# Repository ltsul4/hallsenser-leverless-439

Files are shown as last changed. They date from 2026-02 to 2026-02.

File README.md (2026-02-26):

# Magnetic Leverless Controller (自作磁気接点レバーレス)

本プロジェクトは、磁気スイッチ（ホールセンサー）を採用した超低遅延・高機能な競技用レバーレスコントローラーの開発プロジェクトです。

卒業制作の一環として制作されており、進捗に合わせて随時コードやデータの更新を行います。

---

## 概要

従来の物理接点スイッチではなく、磁力による非接触検知を採用することで、物理的な摩耗を抑えつつ、ミリ単位での高度な入力制御を実現しています。

### 主な機能

* **ラピッドトリガー (Rapid Trigger)**
    指の上げ下げに即座に反応する超高速入力を実現。
* **可変作動点 (Actuation Point)**
    反応する深さを 0.1mm 単位でカスタマイズ可能。
* **Web Configurator**
    専用ソフト不要。ブラウザからリアルタイムに設定変更・モニタリングが可能。
* **SOCDクリーナー**
    競技ルールに準拠した同時押し処理（ニュートラル優先、後押し優先等）を実装。
* **コンボボタン機能**
    1つのボタンで複数のボタン同時押しを再現する補助機能（C1～C4）。
* **入力切断機能**
    設定中の誤入力を防ぐためのセーフティ機能。

---

## ハードウェア設計

設計データはすべて `PCB` フォルダ内に格納されています。

* **基板データ (PCB Design)**: 回路図および基板発注用のガーバーデータ。
* **筐体データ (Acrylic Case)**: レーザーカット用のアクリルパネル設計データ。

### 主要コンポーネント

* **MCU**: STM32F303CBT6
* **センサー**: GH39F ホールセンサー
* **スイッチ**: 
    * デフォルト: Gateron Magnetic Jade Ultra (3.2mmストローク)
    * 特別仕様: Gateron Magnetic Jade Pro (3.5mmストローク)
* **マルチプレクサ**: ADG708

> [!NOTE]
> 本リポジトリの標準ファームウェアは **3.2mmストローク (Jade Ultra)** に最適化されています。
> 3.5mmストロークのスイッチを使用する場合は、`main.c` 内の `TRAVEL_DISTANCE_MM` を `3.5f` に変更してビルドしてください。

---

## ディレクトリ構成

*(※必要に応じて追記してください)*

---

## 導入手順

### 1. ファームウェアの書き込み

1.  [STM32CubeProgrammer](https://www.st.com/ja/development-tools/stm32cubeprog.html) をダウンロードしてPCにインストールします。
2.  基板の裏面にある2つのボタンのうち、**上側のBOOTボタンを押しながら**PCとUSBケーブルで接続します。その後、STM32CubeProgrammerを起動します。
3.  画面右側の接続メニューから「USB」を選択し、「Port」のドロップダウンから適切なポート（例: `USB1`）を選んだ後、緑色の**「Connect」**ボタンをクリックして基板と接続します。

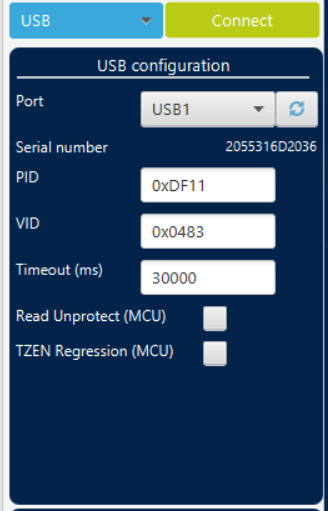
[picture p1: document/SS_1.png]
STM32CubeProgrammerの接続設定
    

4.  接続が成功したら、画面左上の「Open file」タブをクリックします。
5.  ファイル選択ダイアログが開くので、ビルド済みの `.bin` ファイル（例: `Leverless_Controller.bin`）を選択して開きます。

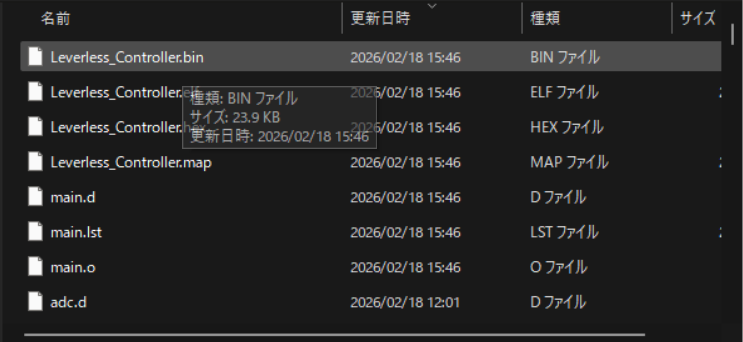
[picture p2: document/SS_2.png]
バイナリファイルの選択
    

6.  ファイルを読み込んだ後、「Download」ボタンをクリックしてファームウェアの書き込み（インストール）を実行します。
7.  **書き込み完了後、USBケーブルを一度抜き、ボタンを押さずにそのまま再度PCへ接続し直してください。**

### 2. 起動モードの選択

本デバイスには2つの動作モードがあります。

* **ゲームモード (通常起動)**
    そのままUSBを接続します。Windowsから「Xbox 360 Controller」として認識され、すぐにゲームで使用可能です。

* **設定モード (ボタン押下起動)**
    **UPボタン**を押しながらUSBを接続し、**数秒待ってから指を離します**。
    カスタムHIDデバイスとして認識され、ブラウザからの設定が可能になります。

### 3. Web Configurator による設定と使い方

1.  **設定モードで起動**
    前述の通り、UPボタンを押しながらデバイスをPCに接続します。
2.  **ブラウザで設定ページを開く**
    使用しているキースイッチに合わせて、以下のいずれかのページをブラウザ（Chrome/Edge推奨）で開きます。
    * **通常版 (3.2mm / Jade Ultra 等):** [WebDriver.htmlを開く](https://ltsul4.github.io/hallsenser-leverless-439/WebDriver/WebDriver.html)
    * **特別版 (3.5mm / Jade Pro 専用):** [WebDriver3.5.htmlを開く](https://ltsul4.github.io/hallsenser-leverless-439/WebDriver/WebDriver3.5.html)
3.  **デバイスの接続**
    画面右上の「接続」ボタンを押し、リストから該当する端末を選択して接続します。
    > ⚠️ **注意:** 端末選択画面で「Xbox 360 Controller」等の表示が出る場合は、設定モードでの接続が失敗しています。一度ケーブルを抜き、再度UPボタンを確実に押しながらつなぎ直してください。

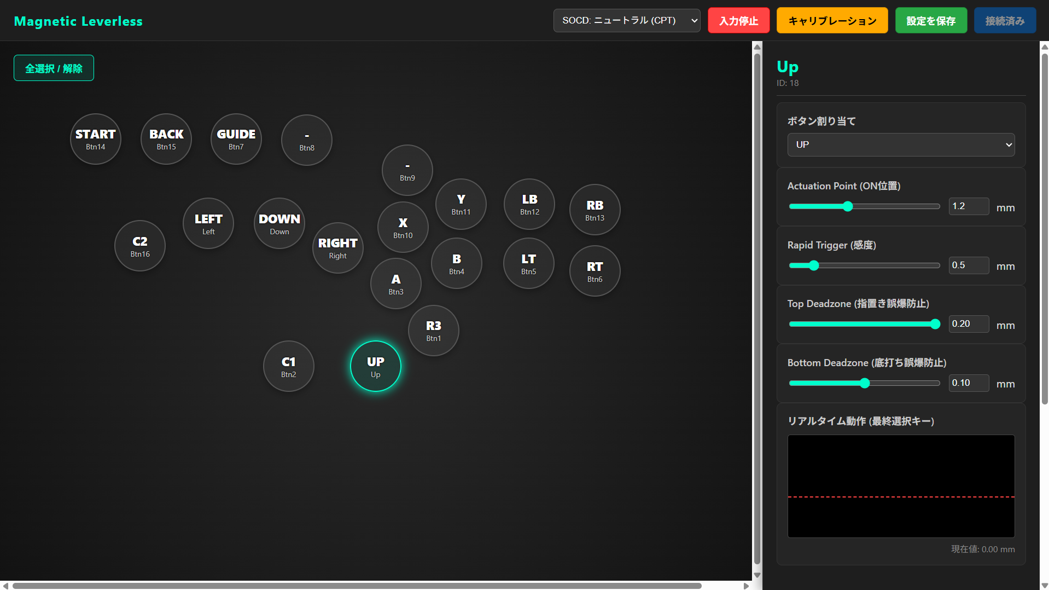
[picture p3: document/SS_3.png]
Web Configuratorのメイン画面
    

4.  **各種設定の調整**
    接続が完了すると、専用ドライバー上で以下の設定が可能になります。
    * **キーマッピング:** 各ボタンへの入力割り当てを変更。
    * **入力感度の調整:** Actuation Point (AP: 作動点)、Rapid Trigger (RT: 感度)、Top/Bottom Deadzone (DZ: 指置き・底打ち時の誤爆防止) をスライダーで設定。
    * **リアルタイム動作:** 右下のグラフで、選択したボタン（画像ではUPボタン）のトラッキング状況をリアルタイムに確認。
    * **SOCD設定:** 画面上部のメニューからSOCDクリーナーの方式を選択。

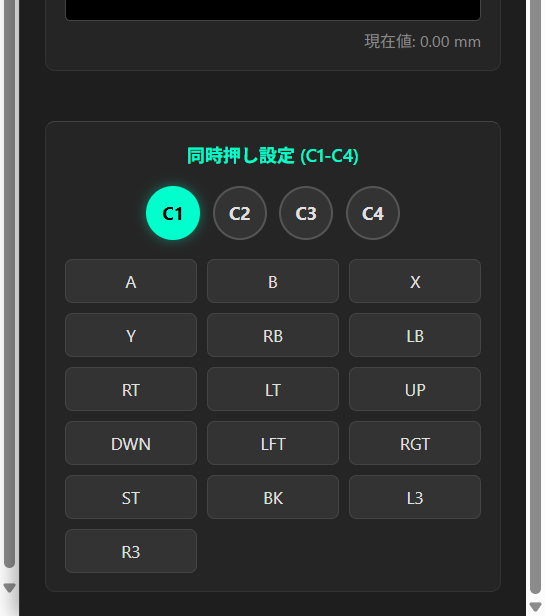
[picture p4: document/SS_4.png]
同時押し設定画面
    

5.  **同時押し設定 (コンボ機能)**
    画面を下にスクロールすると、C1～C4までの4種類の補助ボタンの設定項目があります。ここで複数ボタンの同時押しを登録することができます。
6.  **設定の保存**
    すべての設定が完了したら、画面右上の緑色の**「設定を保存」**ボタンを押します。
7.  **再起動して完了**
    保存完了後、**端末（USBケーブル）を一度抜き、そのまま再度つなぎ直す**ことで、設定がゲームモードに反映されます。

---

## 開発状況

- [x] ホールセンサーによるアナログ値の取得
- [x] ラピッドトリガー・可変作動点アルゴリズムの実装
- [x] WebHID / WebUSB による設定ツールの構築 (`WebDriver.html`)
- [x] Flashメモリへの設定保存機能
- [x] 同時押し（コンボ）ボタン機能の実装

---

## クレジット・参考元

本プロジェクトの制作にあたり、以下のプロジェクトを参考にさせていただきました。
* **参考元:** [kenyoshizoe/ember](https://github.com/kenyoshizoe/ember)

また、本プロジェクトのコードおよびドキュメントの一部は、**Gemini** を活用して作成されました。

---

## ライセンス

**MIT License**

本プロジェクトは卒業制作として継続的に開発されています。温かい目で見守っていただければ幸いです。

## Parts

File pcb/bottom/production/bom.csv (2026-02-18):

Designator | Footprint | Quantity | Value | LCSC Part #
H6 | MountingHole_2.2mm_M2 | 1 | MountingHole

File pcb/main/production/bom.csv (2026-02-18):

Designator | Footprint | Quantity | Value | LCSC Part #
C1, C11, C12, C13, C14, C15, C16, C17, C2, C3, C4, C8 | 0603 | 12 | 100n | C14663
C10 | 0603 | 1 | 22u | C59461
C5 | 0603 | 1 | 10n | C57112
C6, C7 | 0603 | 2 | 10p | C1634
C9 | 0603 | 1 | 10u | C19702
D1 | 0603 | 1 | LED | C72043
H1, H2, H3, H39, H4, H40, H5, H6 | MountingHole_2.2mm_M2 | 8 | MountingHole
H10, H11, H12, H13, H14, H15, H16, H17, H18, H19, H20, H21, H22, H23, H24, H25, H26, H7, H8, H9 | MX-1U-NoPins | 20 | KeySwitch
IC1 | SOIC127P600X175-8N | 1 | M24C64-RMN6TP | C79988
IC2, IC3, IC4 | SOP65P640X120-16N | 3 | ADG708BRUZ-REEL7 | C35325
J1 | USB_C_Receptacle_XKB_U262-16XN-4BVC11 | 1 | USB_C_Receptacle_USB2.0 | C319148
J2 | PinSocket_1x05_P2.54mm_Vertical | 1 | Conn_01x05_Socket
MCU1 | LQFP-48_7x7mm_P0.5mm | 1 | STM32F303CBTx | C108516
R1, R2 | 0603 | 2 | 5.1k | C23186
R3 | 0603 | 1 | 1.5k | C22843
R4, R8 | 0603 | 2 | 1k | C21190
R5, R6 | 0603 | 2 | 10k | C25804
R7 | 0603 | 1 | 470 | C23179
SW1 | SW_Push_1P1T_XKB_TS-1187A | 1 | BOOT | C318884
SW2 | SW_Push_1P1T_XKB_TS-1187A | 1 | RESET | C318884
U1 | SOT-23-6 | 1 | SRV05-4 | C85364
U10, U11, U12, U13, U14, U15, U16, U17, U18, U19, U20, U21, U22, U3, U4, U5, U6, U7, U8, U9 | SOT-23 | 20 | Hall_Sensor | C266230
U2 | SOT-223-3_TabPin2 | 1 | AMS1117-3.3 | C6186
Y1 | Crystal_SMD_3225-4Pin_3.2x2.5mm | 1 | 16MHz | C13738

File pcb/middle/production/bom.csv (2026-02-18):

Designator | Footprint | Quantity | Value | LCSC Part #
H1, H2, H3, H39, H4, H40, H5, H6 | MountingHole_2.2mm_M2 | 8 | MountingHole

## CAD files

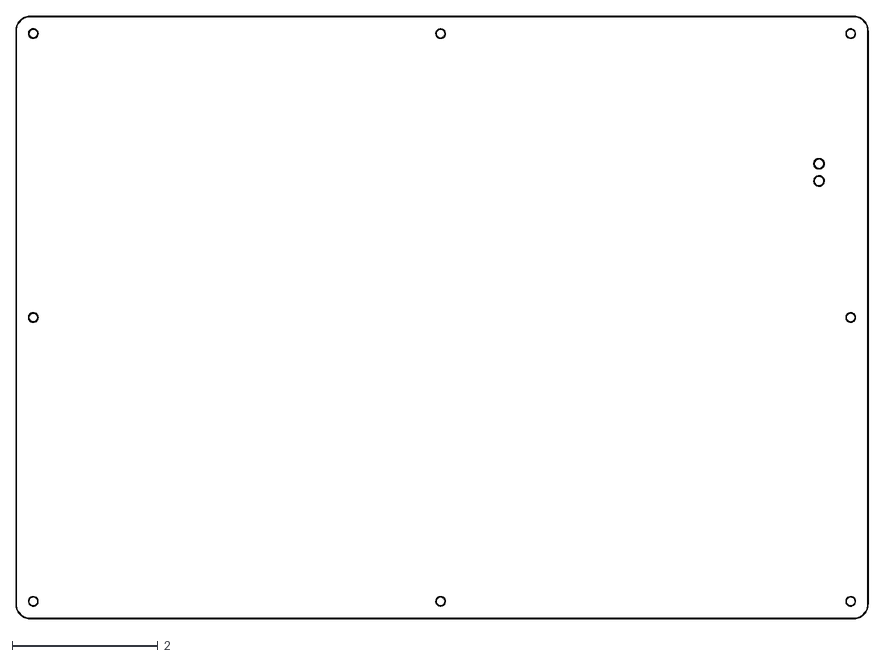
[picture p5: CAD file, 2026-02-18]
pcb/acrylic/元データ/1bottom_bottom/bottom2.dxf
11.7 x 8.27

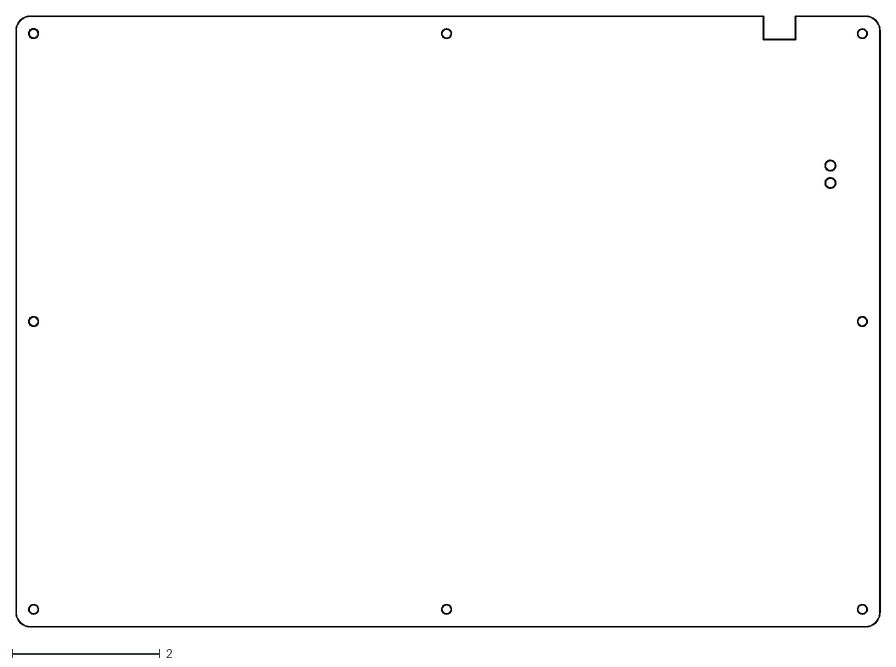
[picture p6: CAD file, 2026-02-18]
pcb/acrylic/元データ/1bottom_top/bottom1.dxf
11.7 x 8.27

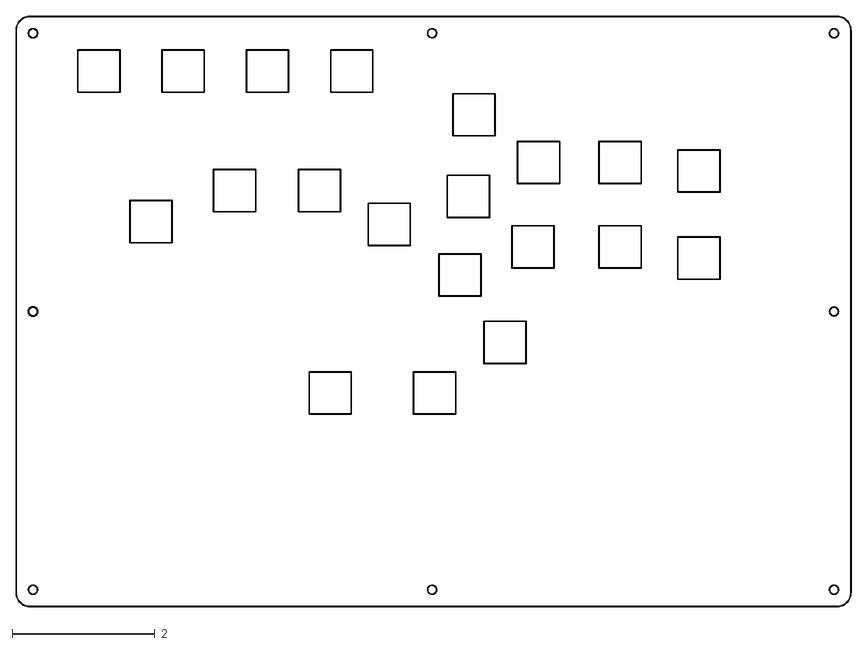
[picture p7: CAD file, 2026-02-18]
pcb/acrylic/元データ/1middle/middle.dxf
11.7 x 8.27

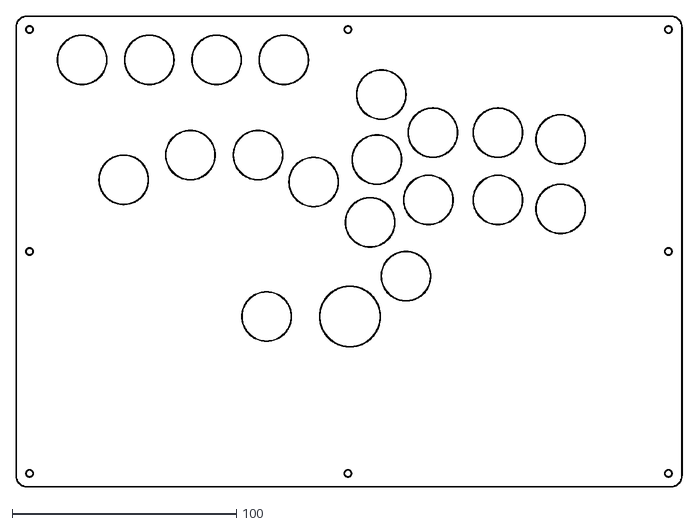
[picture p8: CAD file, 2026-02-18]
pcb/acrylic/元データ/1top1/top1.dxf
297.1 x 210.1

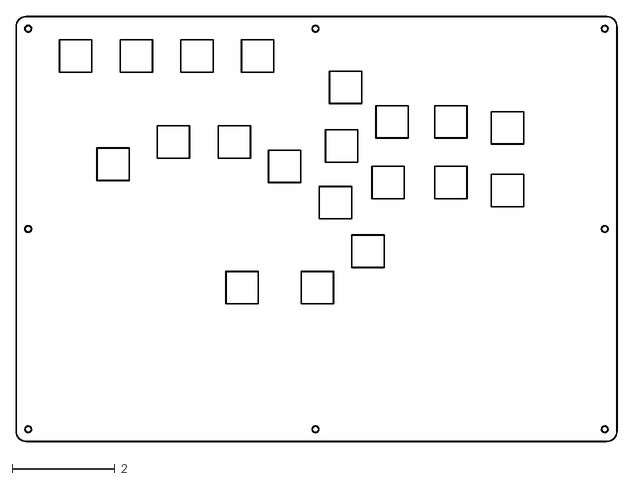
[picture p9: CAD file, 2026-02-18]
pcb/acrylic/元データ/1top2/top2.dxf
11.7 x 8.27

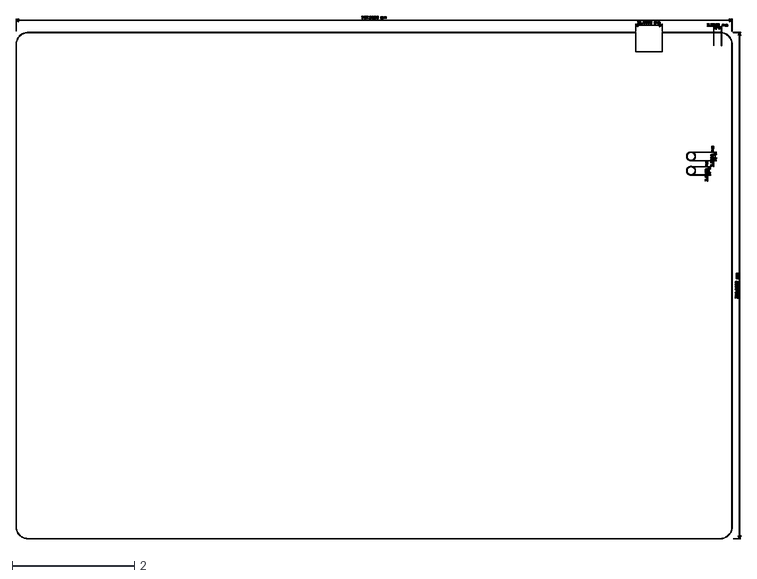
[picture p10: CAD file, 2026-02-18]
pcb/acrylic/元データ/kicad_bottom1/ember-Edge_Cuts.dxf
11.8 x 8.54

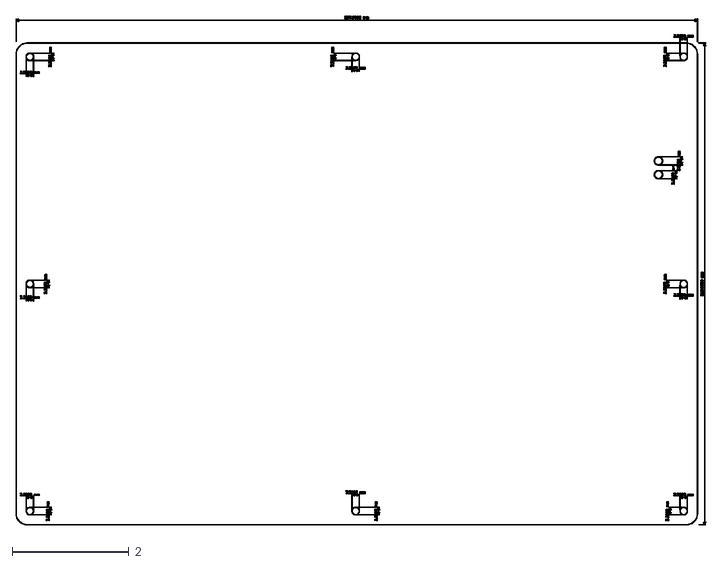
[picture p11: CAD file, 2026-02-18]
pcb/acrylic/元データ/kicad_bottom_2/ember-Edge_Cuts.dxf
11.8 x 8.73

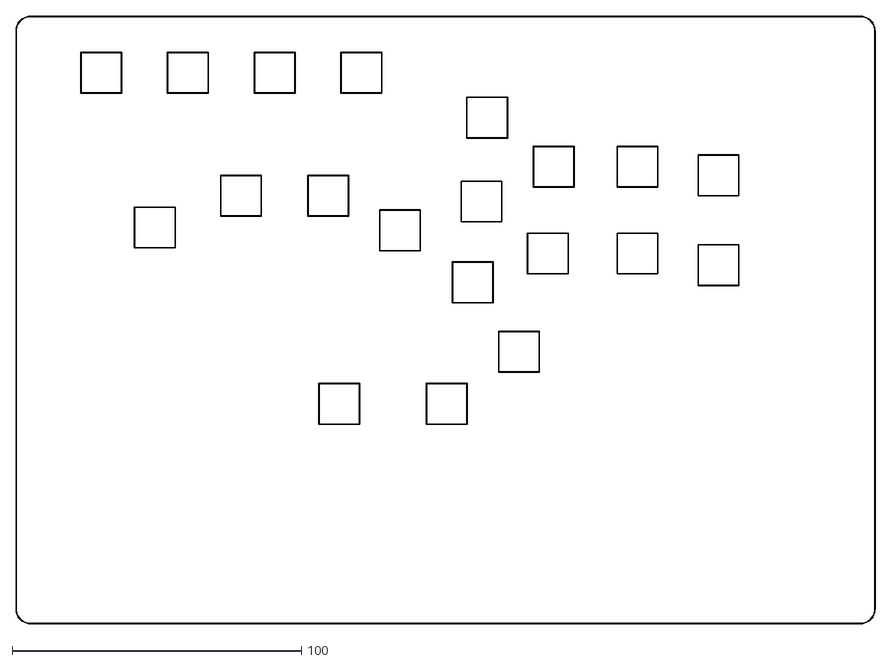
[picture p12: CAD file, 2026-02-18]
pcb/acrylic/元データ/kicad_middle/ember_top_plate-Edge_Cuts.dxf
297.1 x 210.1

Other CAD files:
pcb/acrylic/元データ/kicad_bottom_2/ember-B_Mask.dxf

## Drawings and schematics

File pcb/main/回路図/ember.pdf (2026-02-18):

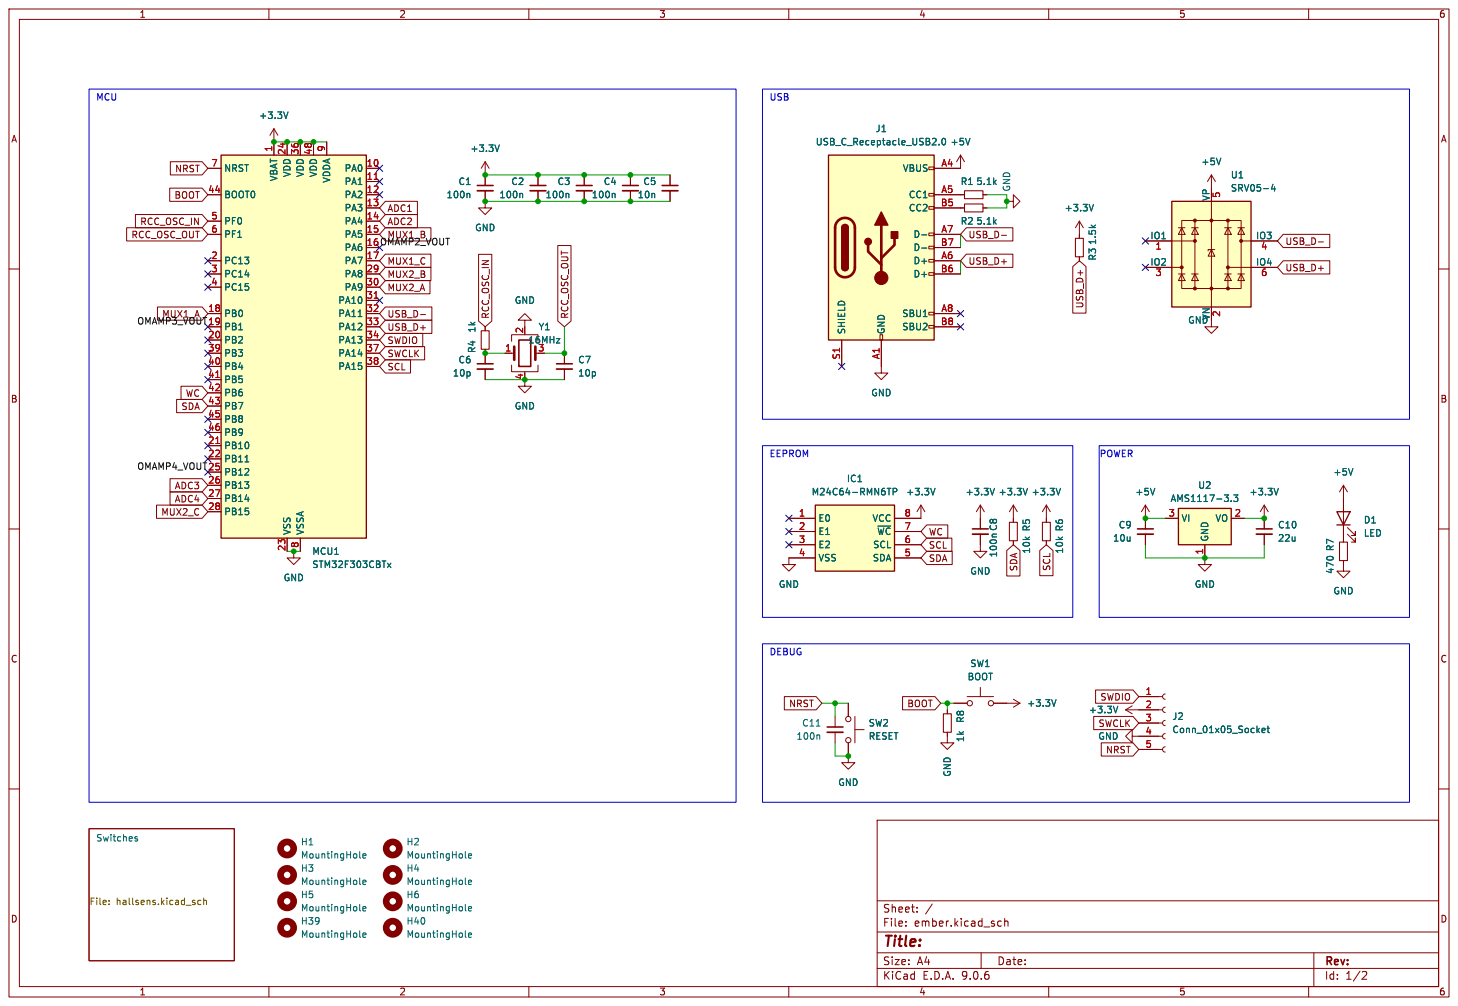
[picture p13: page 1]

1 VDD 24 VSS 23 VDD 36 VSSA

+3.3V H4 MountingHole H5 MountingHole H39 MountingHole H3 MountingHole H1 MountingHole

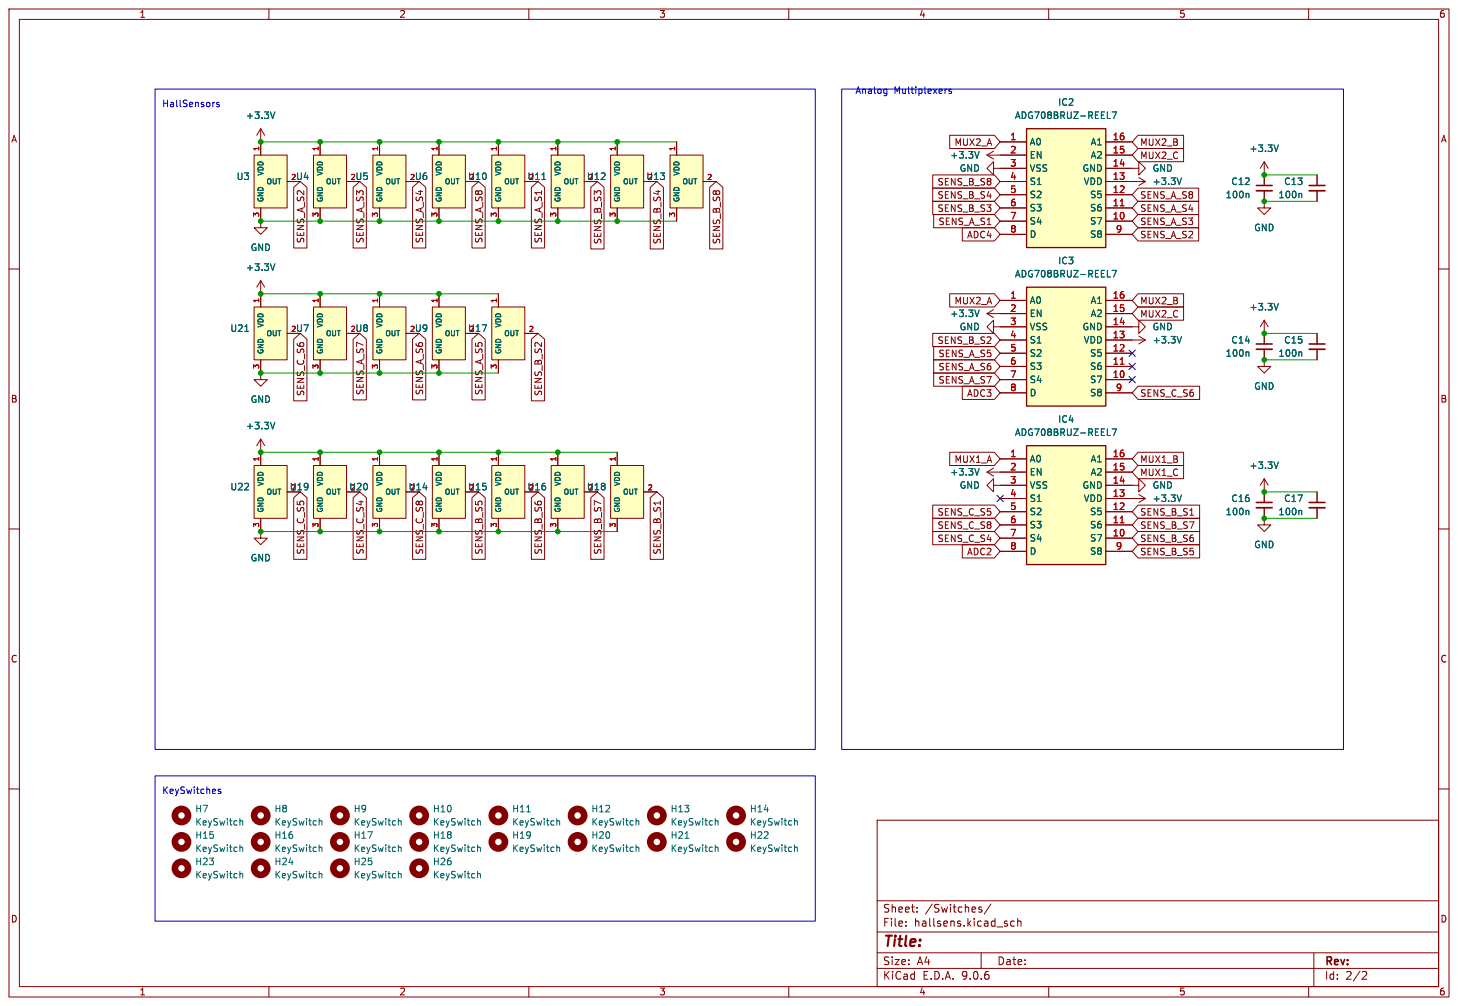
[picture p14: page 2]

3 OUT U10 2 H18 KeySwitch H19 KeySwitch H12 KeySwitch H20 KeySwitch H11 KeySwitch VDD

Id: 2/2 Title: File: hallsens.kicad_sch Sheet: /Switches/

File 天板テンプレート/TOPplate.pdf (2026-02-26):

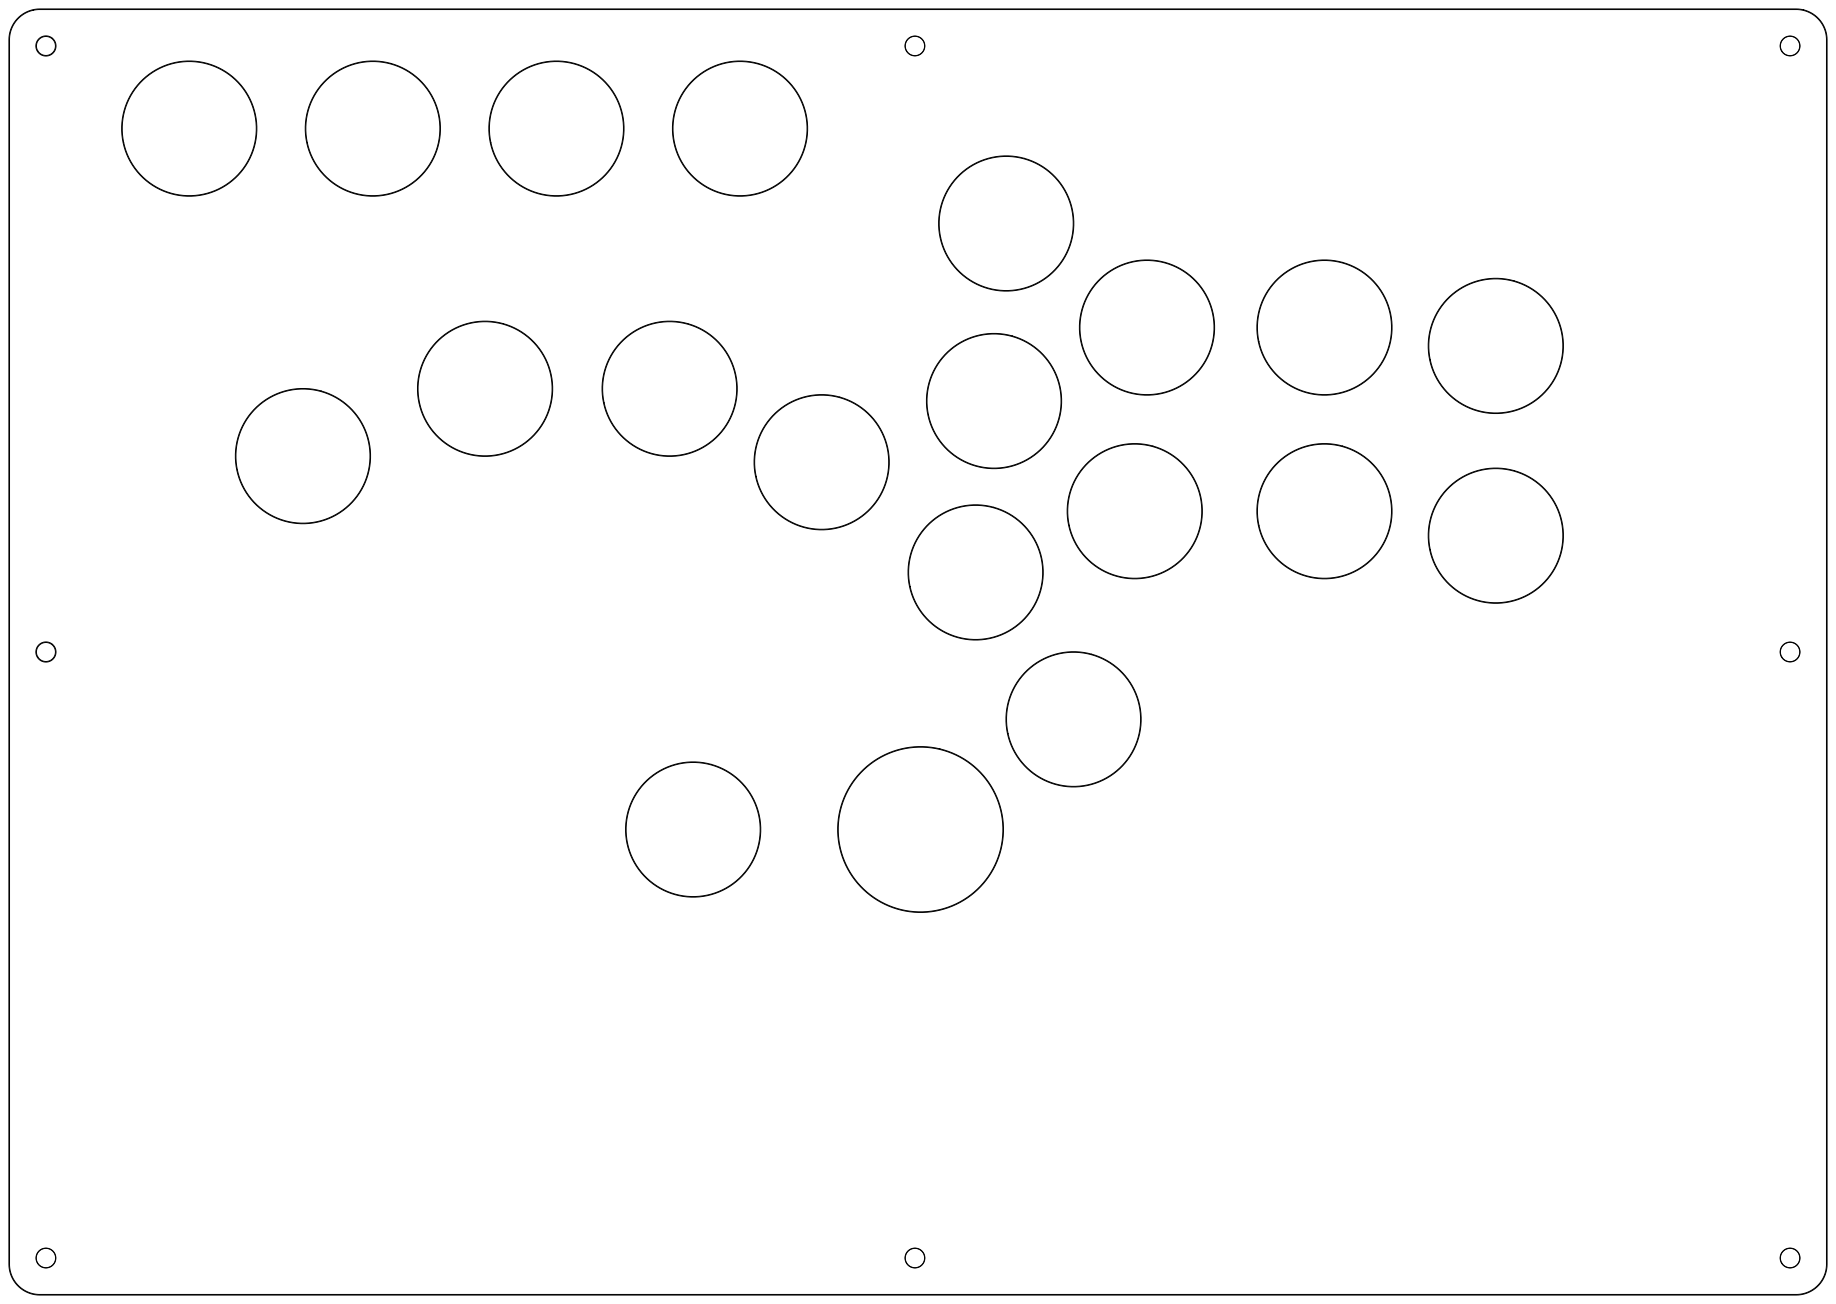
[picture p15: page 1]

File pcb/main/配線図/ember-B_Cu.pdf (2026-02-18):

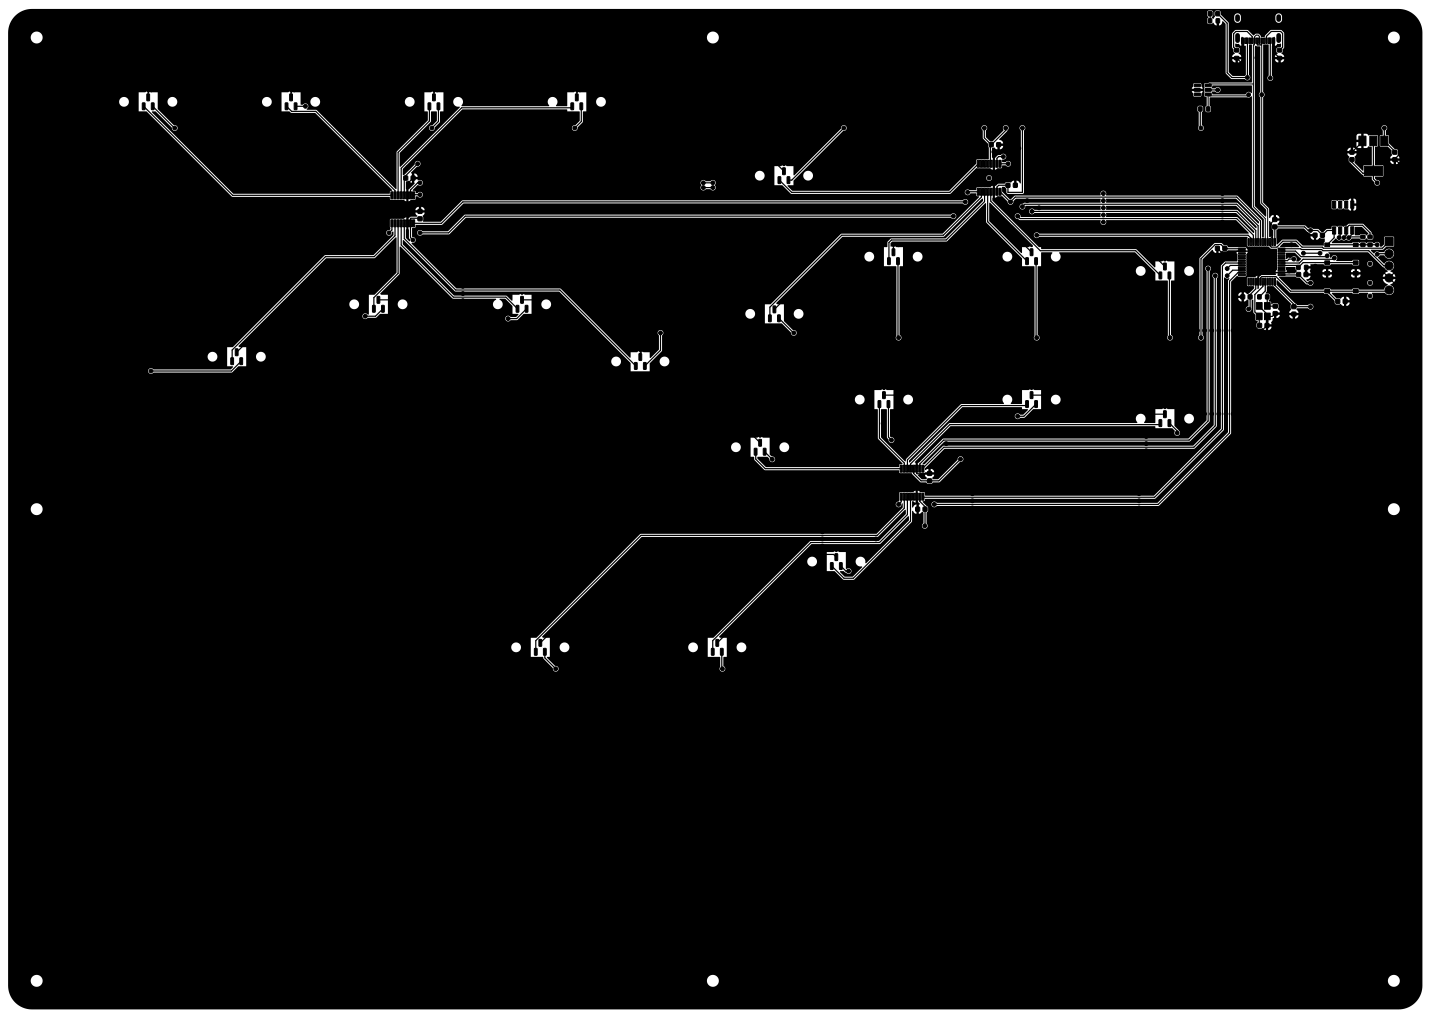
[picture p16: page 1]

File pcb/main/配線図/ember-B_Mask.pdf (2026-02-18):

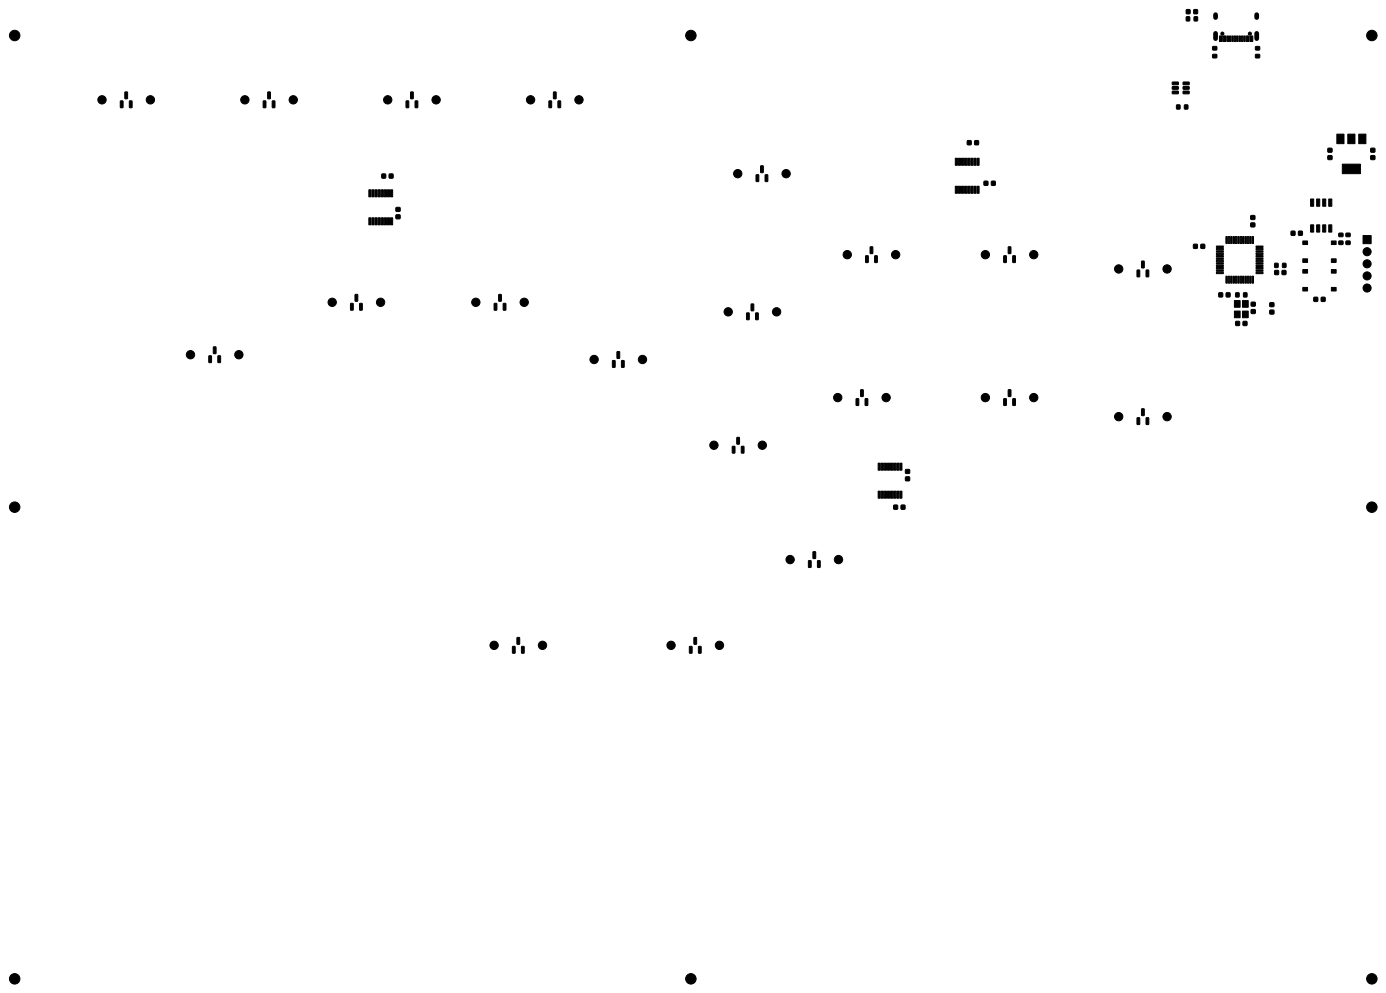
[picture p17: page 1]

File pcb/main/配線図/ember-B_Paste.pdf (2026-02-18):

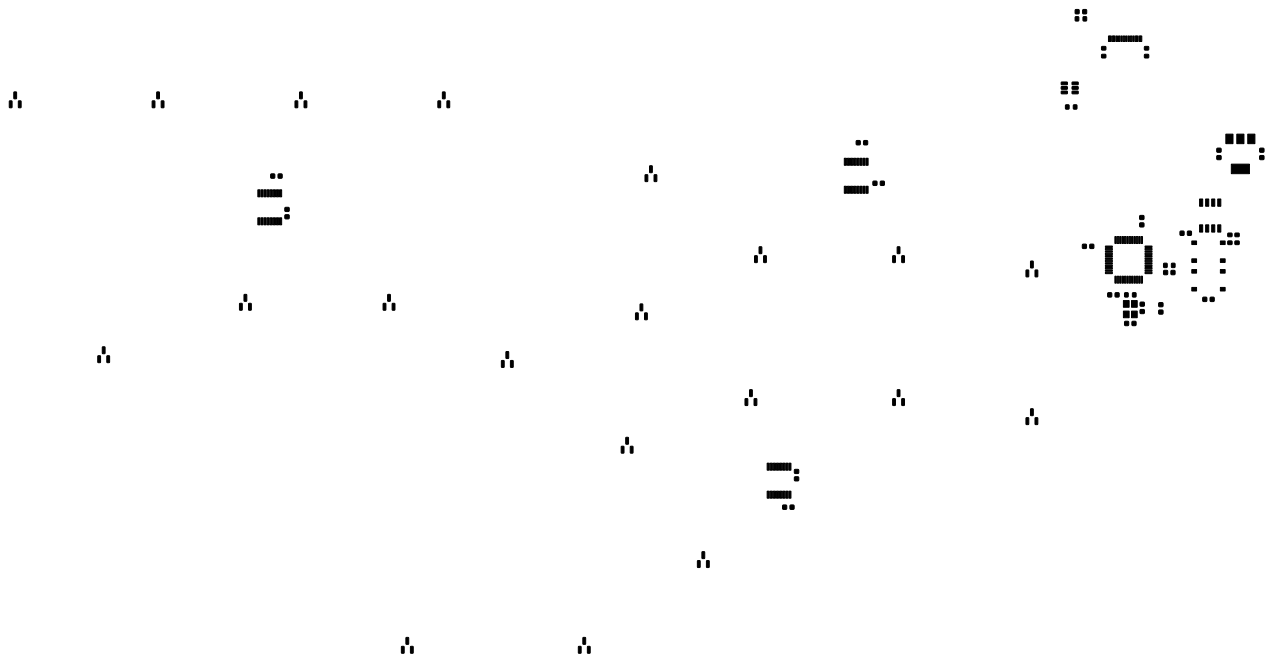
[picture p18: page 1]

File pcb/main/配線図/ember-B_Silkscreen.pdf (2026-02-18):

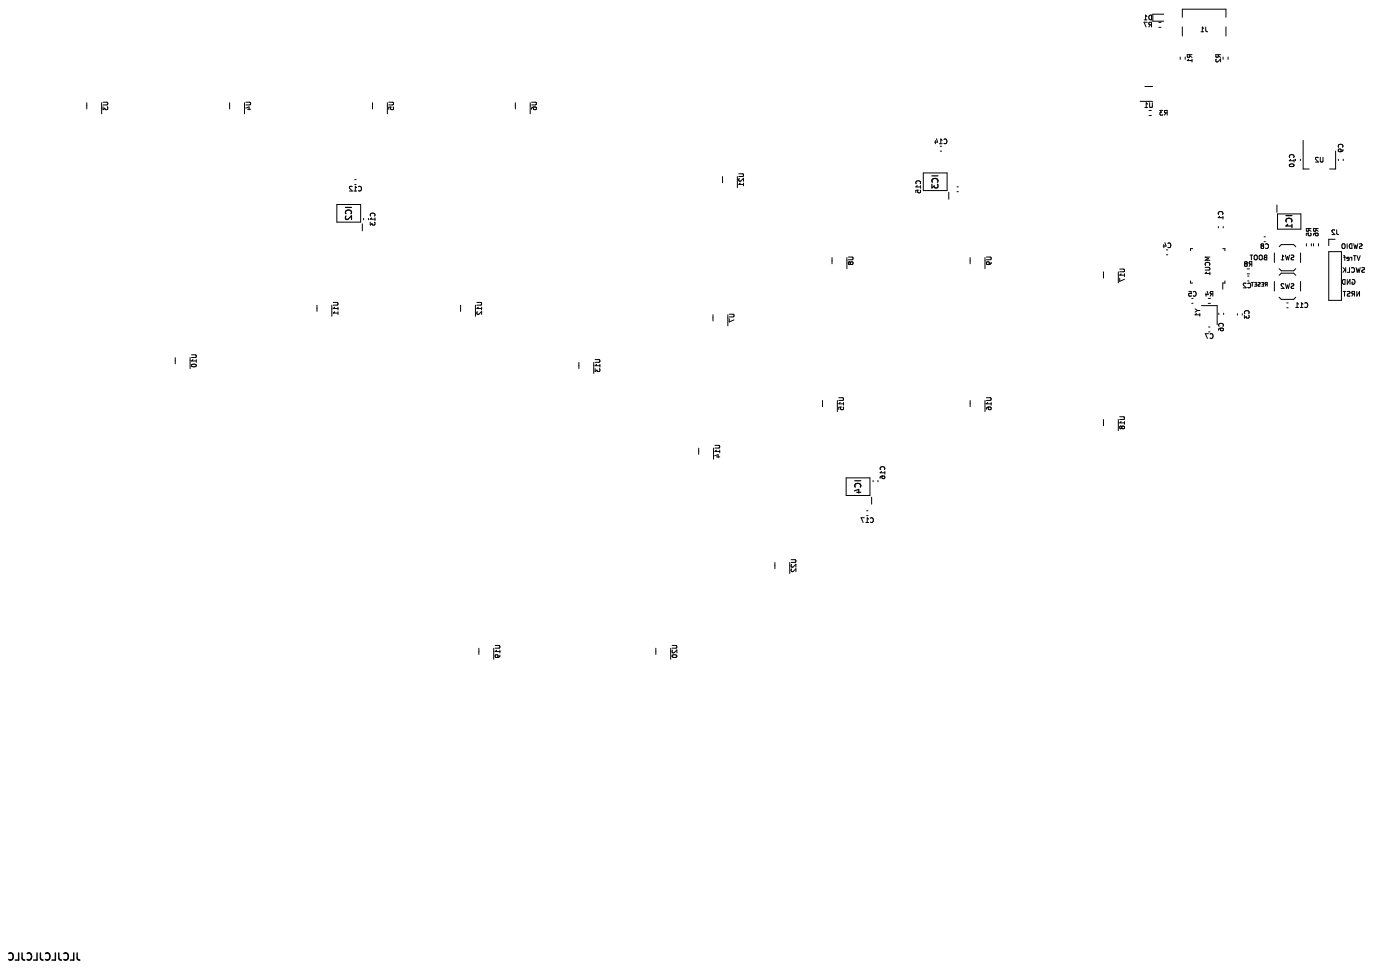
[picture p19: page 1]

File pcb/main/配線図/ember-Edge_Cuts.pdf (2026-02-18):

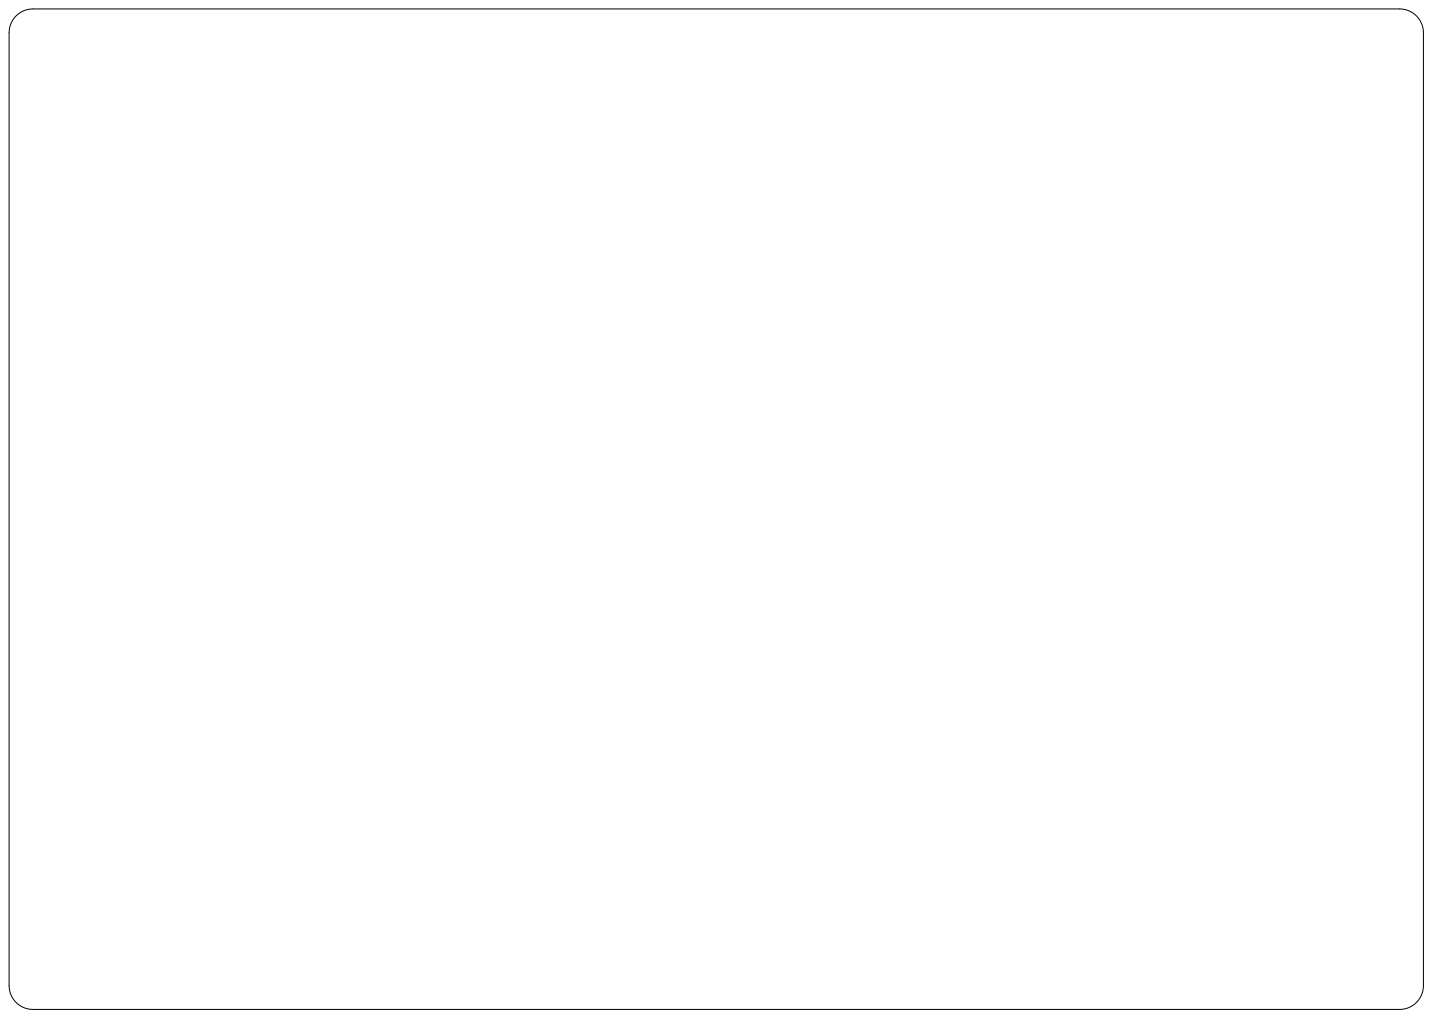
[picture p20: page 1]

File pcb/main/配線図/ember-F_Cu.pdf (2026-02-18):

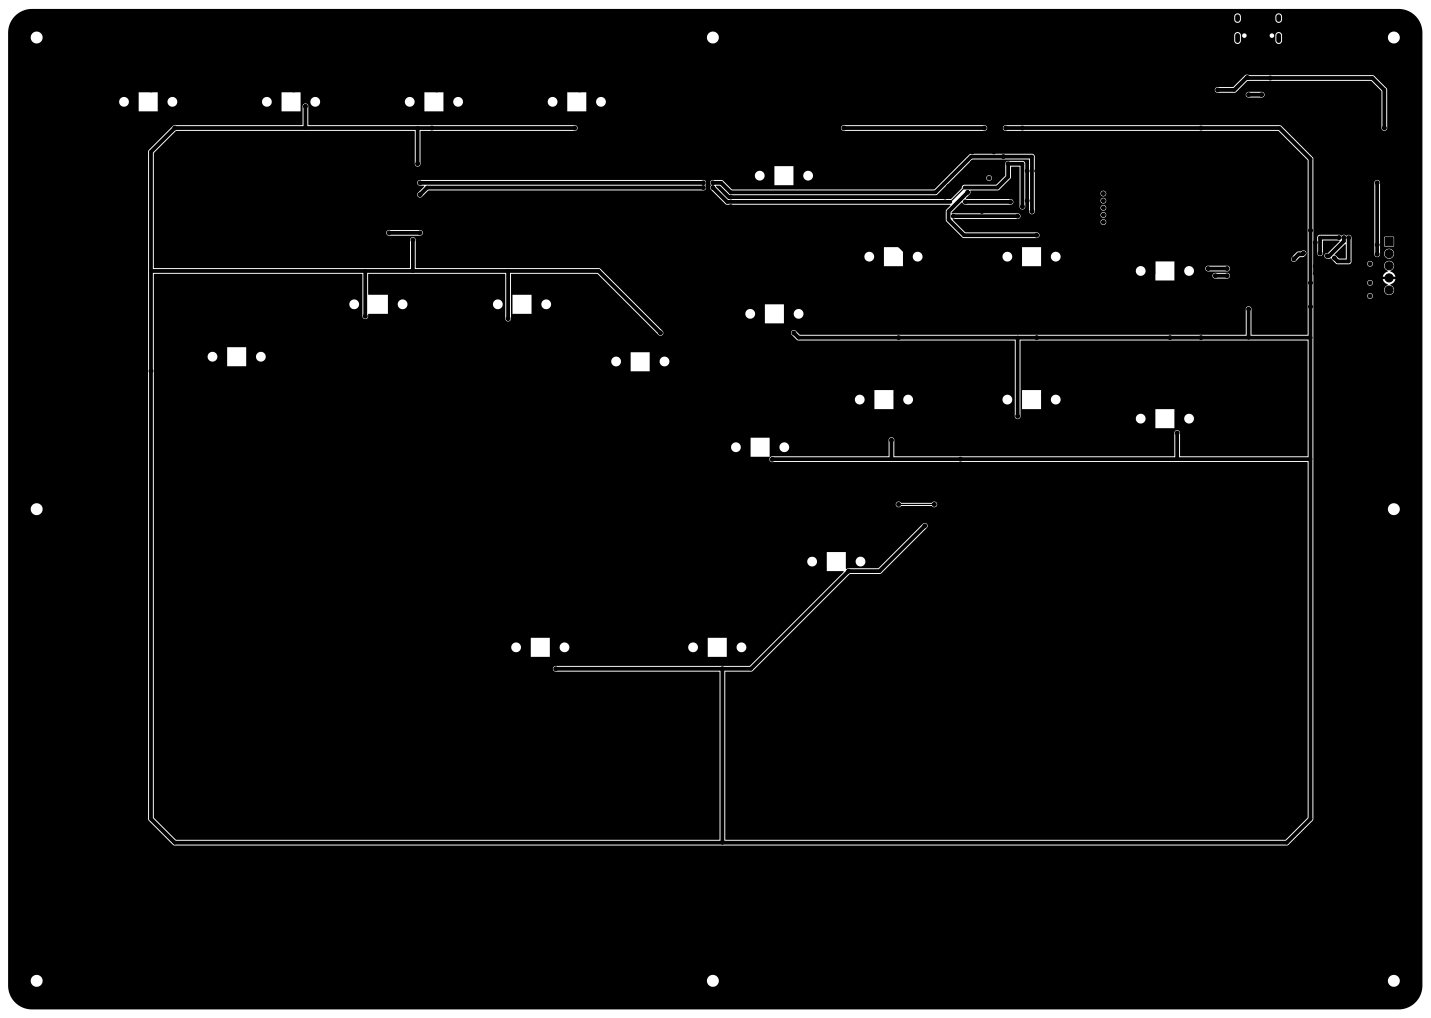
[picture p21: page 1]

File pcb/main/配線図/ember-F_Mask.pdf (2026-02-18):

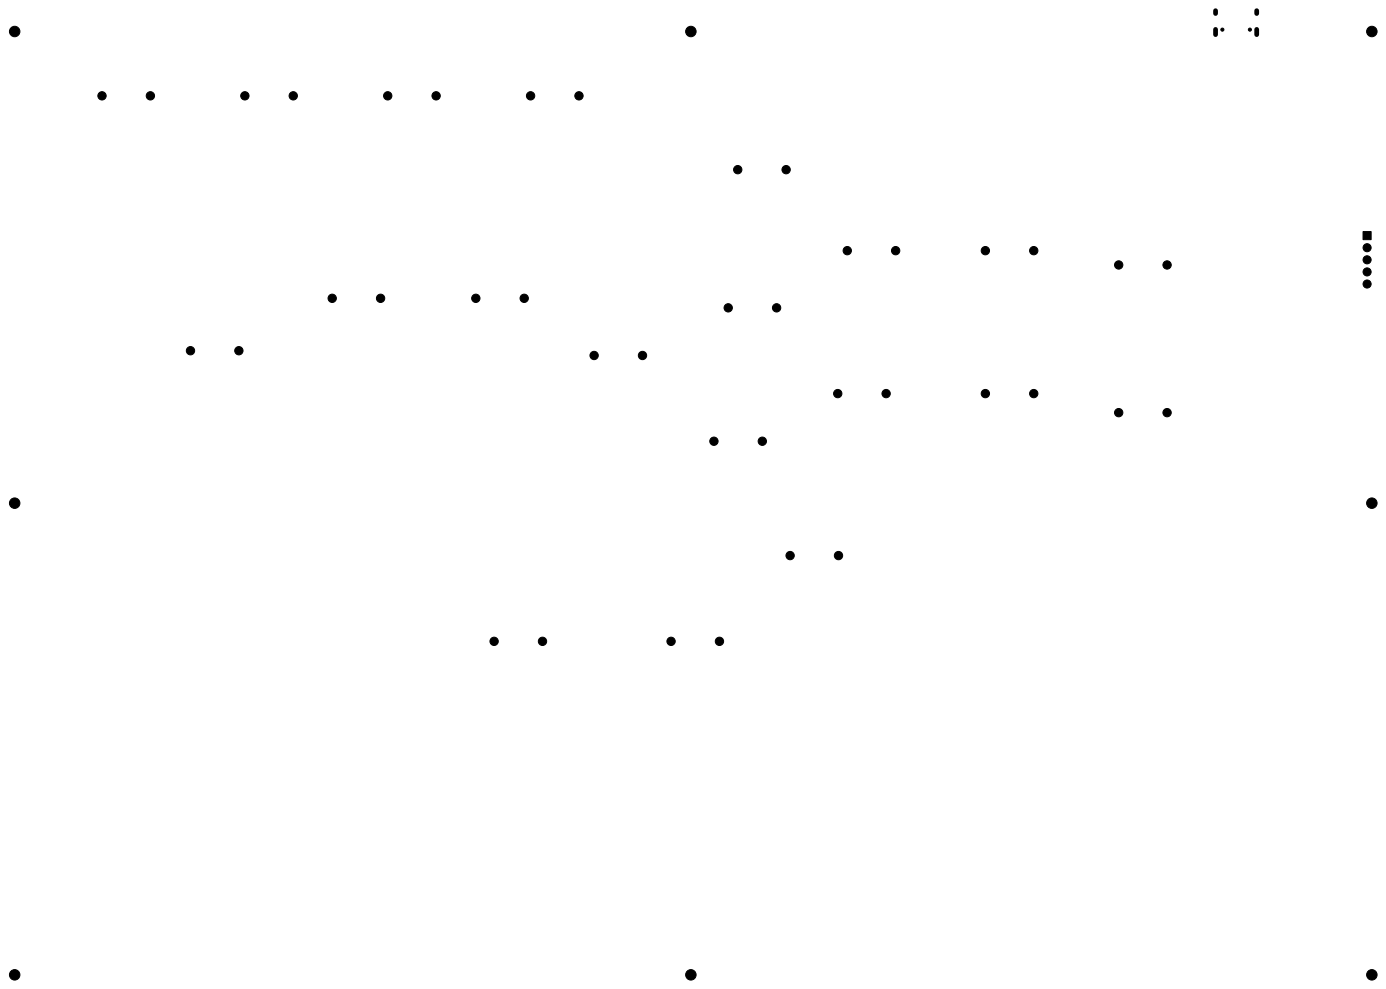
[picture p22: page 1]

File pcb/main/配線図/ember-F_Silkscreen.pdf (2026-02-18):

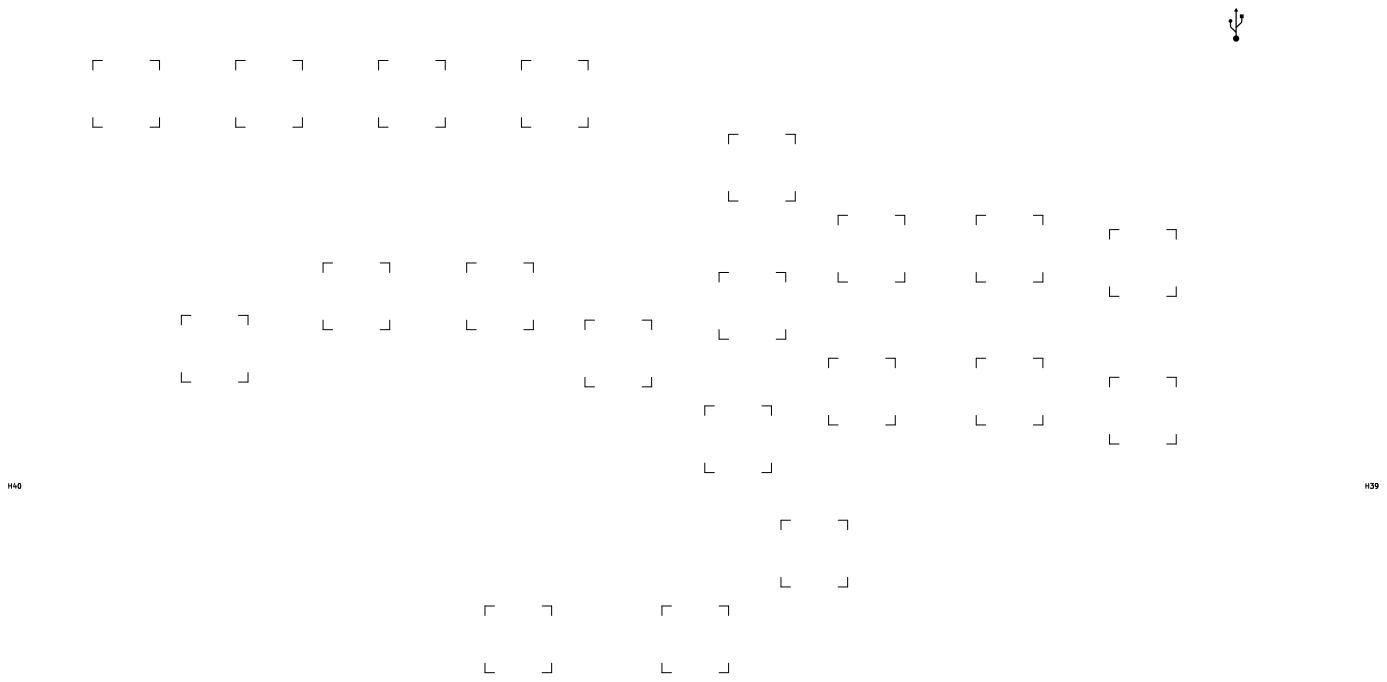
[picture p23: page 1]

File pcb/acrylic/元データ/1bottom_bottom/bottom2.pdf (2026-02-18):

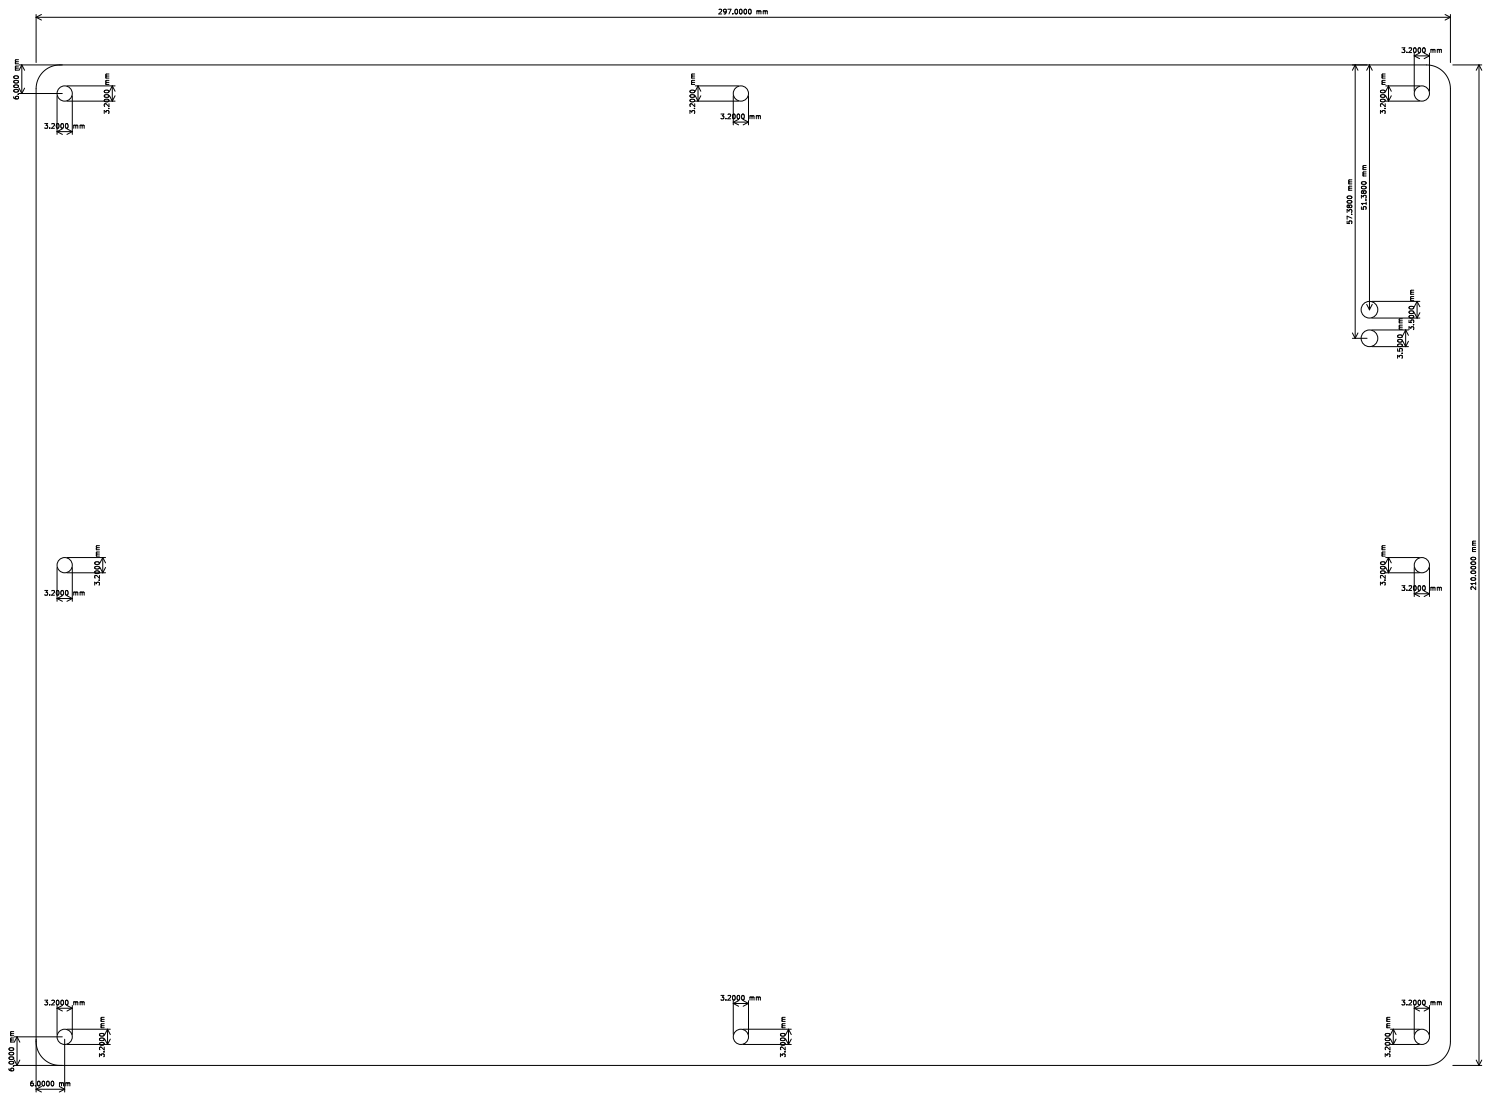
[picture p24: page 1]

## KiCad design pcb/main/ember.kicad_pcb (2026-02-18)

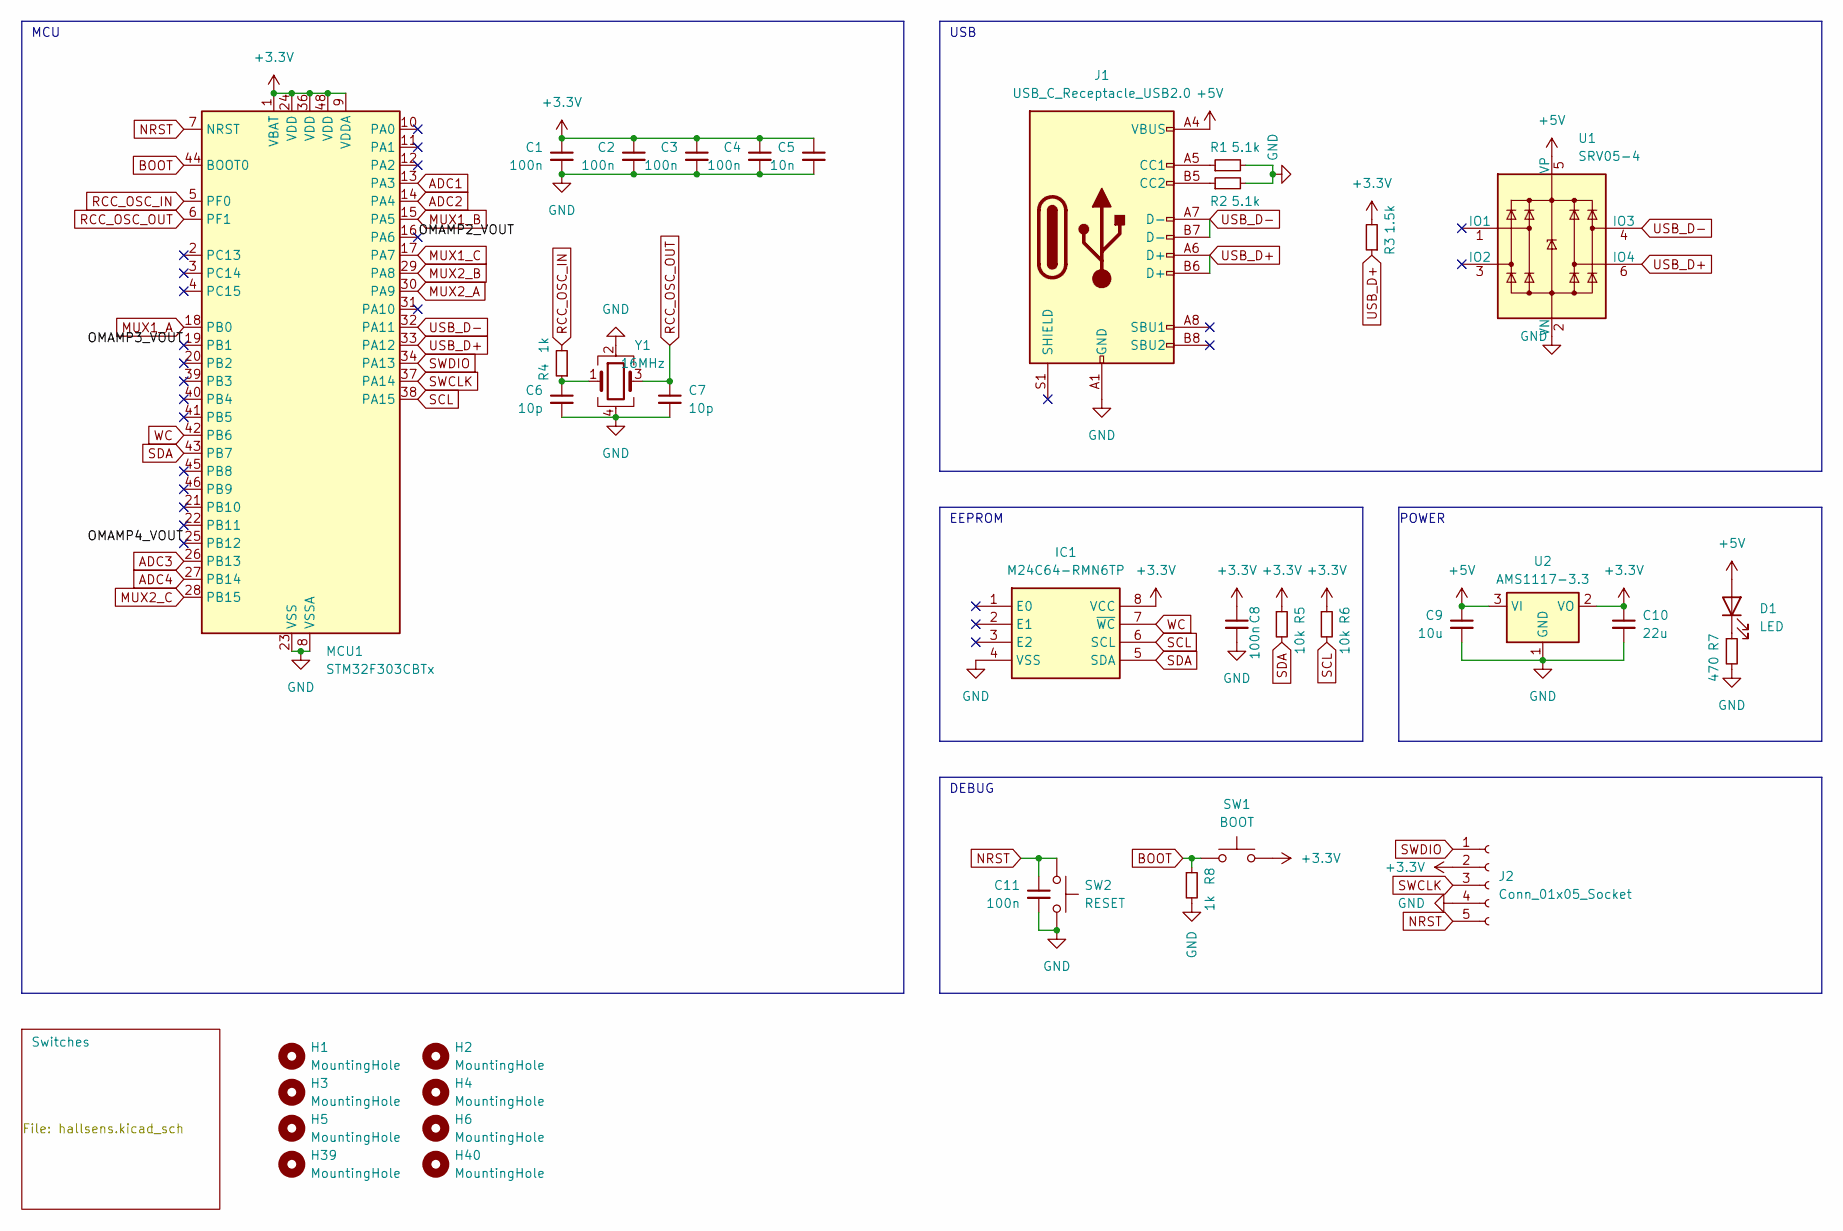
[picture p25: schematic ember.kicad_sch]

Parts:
C1, C2, C3, C4, C8, C11: 100n; C_0603_1608Metric; LCSC C14663
C5: 10n; C_0603_1608Metric; LCSC C57112
C6, C7: 10p; C_0603_1608Metric; LCSC C1634
C9: 10u; C_0603_1608Metric; LCSC C19702
C10: 22u; C_0603_1608Metric; LCSC C59461
D1: LED; LED_0603_1608Metric; LCSC C72043
H1, H2, H3, H4, H5, H6, H39, H40: MountingHole; MountingHole_2.2mm_M2
IC1: M24C64-RMN6TP; SOIC127P600X175-8N; Mouser Part Number 511-M24C64-RMN6TP
J1: USB_C_Receptacle_USB2.0; USB_C_Receptacle_XKB_U262-16XN-4BVC11; LCSC C319148
J2: Conn_01x05_Socket; PinSocket_1x05_P2.54mm_Vertical
MCU1: STM32F303CBTx; LQFP-48_7x7mm_P0.5mm; LCSC C108516
R1, R2: 5.1k; R_0603_1608Metric; LCSC C23186
R3: 1.5k; R_0603_1608Metric; LCSC C22843
R4, R8: 1k; R_0603_1608Metric; LCSC C21190
R5, R6: 10k; R_0603_1608Metric; LCSC C25804
R7: 470; R_0603_1608Metric; LCSC C23179
SW1: BOOT; SW_Push_1P1T_XKB_TS-1187A; LCSC C318884
SW2: RESET; SW_Push_1P1T_XKB_TS-1187A; LCSC C318884
U1: SRV05-4; SOT-23-6; LCSC C85364
U2: AMS1117-3.3; SOT-223-3_TabPin2; LCSC C6186
Y1: 16MHz; Crystal_SMD_3225-4Pin_3.2x2.5mm; LCSC C13738

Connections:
+3.3V: C1.1, C2.1, C3.1, C4.1, C5.1, C8.1, C10.1, IC1.8 (VCC), J2.2, MCU1.1 (VBAT), MCU1.9 (VDDA), MCU1.24 (VDD), MCU1.36 (VDD), MCU1.48 (VDD), R3.2, R5.1, R6.1, SW1.2, U2.2 (VO); also elsewhere on the board
+5V: C9.1, D1.2 (A), J1.A4 (VBUS), J1.A9 (VBUS), J1.B4 (VBUS), J1.B9 (VBUS), U1.5 (VP), U2.3 (VI)
/OMAMP2_VOUT: MCU1.16 (PA6)
/OMAMP3_VOUT: MCU1.19 (PB1)
/OMAMP4_VOUT: MCU1.25 (PB12)
ADC1: MCU1.13 (PA3)
ADC2: MCU1.14 (PA4); also elsewhere on the board
ADC3: MCU1.26 (PB13); also elsewhere on the board
ADC4: MCU1.27 (PB14); also elsewhere on the board
BOOT: MCU1.44 (BOOT0), R8.1, SW1.1
GND: C1.2, C2.2, C3.2, C4.2, C5.2, C6.2, C7.2, C8.2, C9.2, C10.2, C11.2, IC1.4 (VSS), J1.A1 (GND), J1.A12 (GND), J1.B1 (GND), J1.B12 (GND), J2.4, MCU1.8 (VSSA), MCU1.23 (VSS), MCU1.35 (VSS), MCU1.47 (VSS), R1.2, R2.2, R7.2, R8.2, SW2.2, U1.2 (VN), U2.1 (GND), Y1.2, Y1.4; also elsewhere on the board
MUX1_A: MCU1.18 (PB0); also elsewhere on the board
MUX1_B: MCU1.15 (PA5); also elsewhere on the board
MUX1_C: MCU1.17 (PA7); also elsewhere on the board
MUX2_A: MCU1.30 (PA9); also elsewhere on the board
MUX2_B: MCU1.29 (PA8); also elsewhere on the board
MUX2_C: MCU1.28 (PB15); also elsewhere on the board
NRST: C11.1, J2.5, MCU1.7 (NRST), SW2.1
unnamed: C6.1, R4.1, Y1.1
unnamed: D1.1 (K), R7.1
unnamed: J1.A5 (CC1), R1.1
unnamed: J1.B5 (CC2), R2.1
RCC_OSC_IN: MCU1.5 (PF0), R4.2
RCC_OSC_OUT: C7.1, MCU1.6 (PF1), Y1.3
SCL: IC1.6 (SCL), MCU1.38 (PA15), R6.2
SDA: IC1.5 (SDA), MCU1.43 (PB7), R5.2
SWCLK: J2.3, MCU1.37 (PA14)
SWDIO: J2.1, MCU1.34 (PA13)
USB_D+: J1.A6 (D+), J1.B6 (D+), MCU1.33 (PA12), R3.1, U1.6 (IO4)
USB_D-: J1.A7 (D-), J1.B7 (D-), MCU1.32 (PA11), U1.4 (IO3)
WC: IC1.7 (~WC), MCU1.42 (PB6)

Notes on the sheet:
MCU
USB
POWER
EEPROM
DEBUG

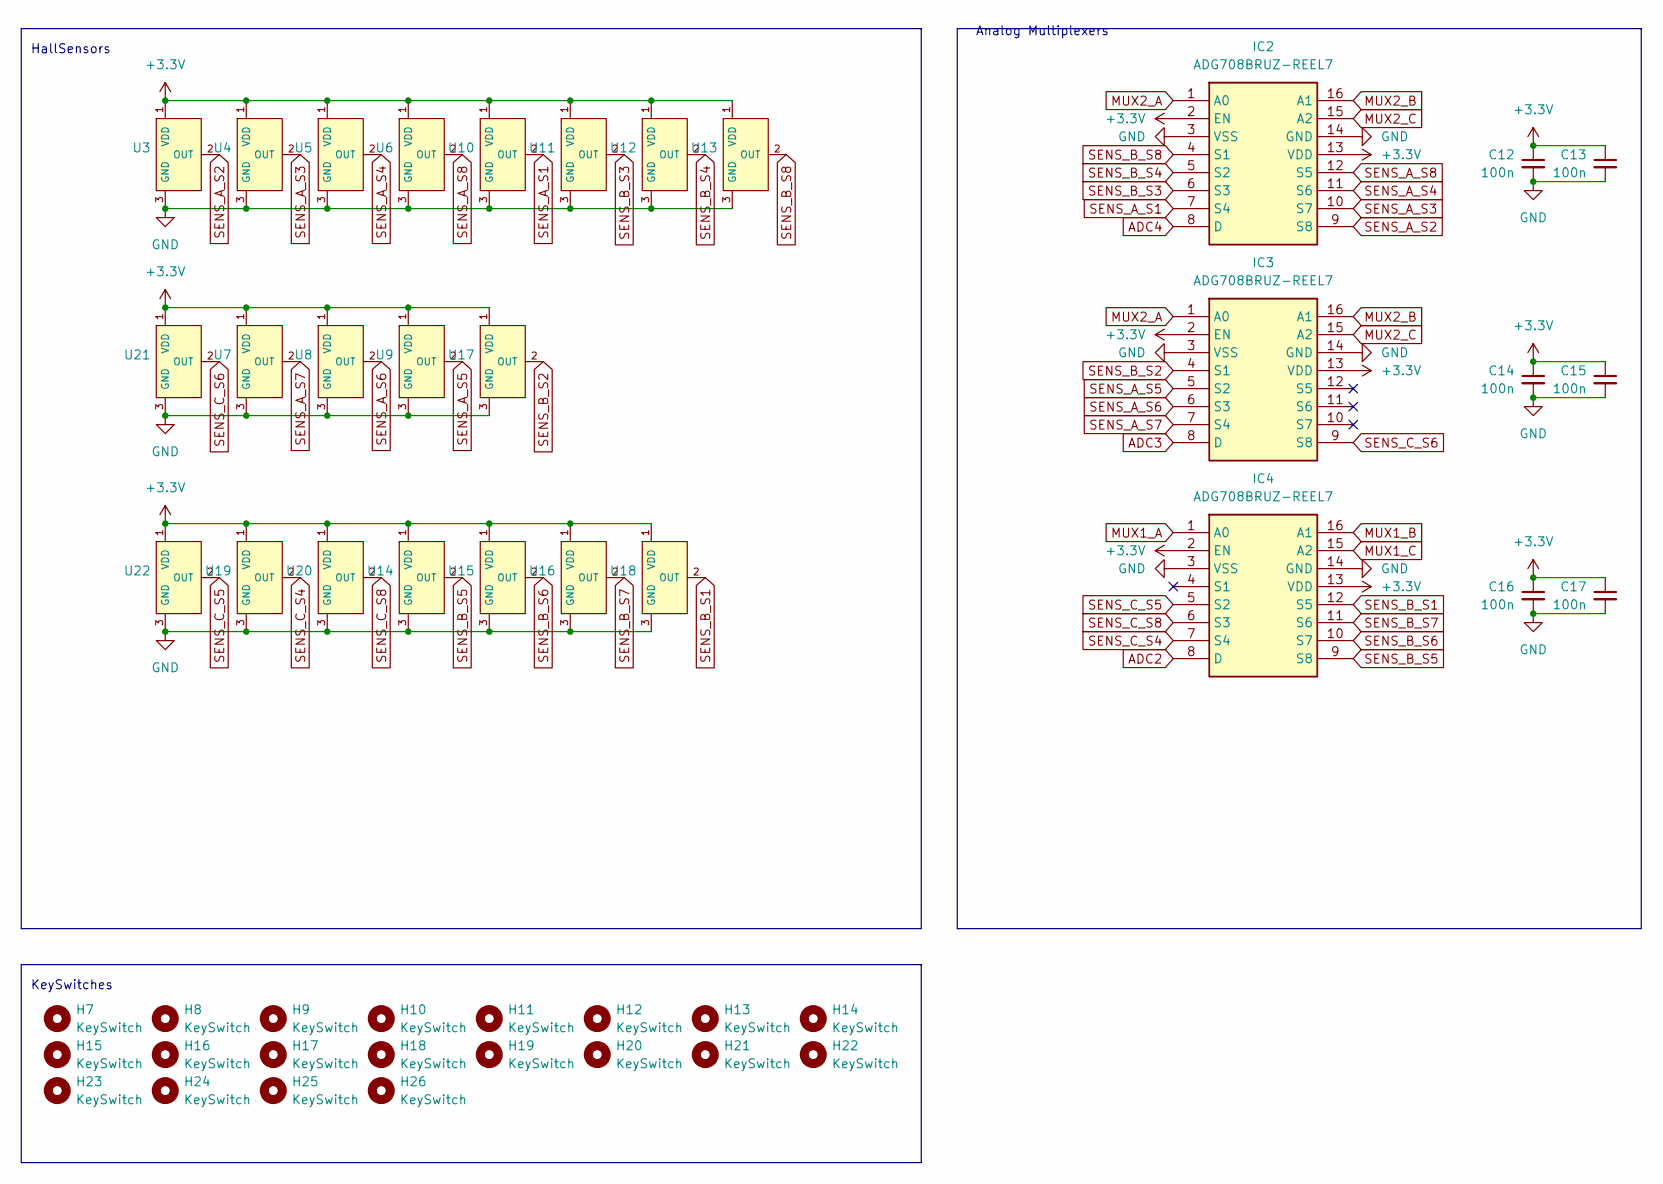
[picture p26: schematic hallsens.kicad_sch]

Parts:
C12, C13, C14, C15, C16, C17: 100n; C_0603_1608Metric; LCSC C14663
H7, H8, H9, H10, H11, H12, H13, H14, H15, H16, H17, H18, H19, H20, H21, H22, H23, H24, H25, H26: KeySwitch; MX-1U-NoPins
IC2, IC3, IC4: ADG708BRUZ-REEL7; SOP65P640X120-16N; Mouser Part Number 584-ADG708BRUZ-R7
U3, U4, U5, U6, U7, U8, U9, U10, U11, U12, U13, U14, U15, U16, U17, U18, U19, U20, U21, U22: Hall_Sensor; SOT-23; MPN SLSS49E-3; LCSC Part C266230

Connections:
+3.3V: C12.1, C13.1, C14.1, C15.1, C16.1, C17.1, IC2.2 (EN), IC2.13 (VDD), IC3.2 (EN), IC3.13 (VDD), IC4.2 (EN), IC4.13 (VDD), U3.1 (VDD), U4.1 (VDD), U5.1 (VDD), U6.1 (VDD), U7.1 (VDD), U8.1 (VDD), U9.1 (VDD), U10.1 (VDD), U11.1 (VDD), U12.1 (VDD), U13.1 (VDD), U14.1 (VDD), U15.1 (VDD), U16.1 (VDD), U17.1 (VDD), U18.1 (VDD), U19.1 (VDD), U20.1 (VDD), U21.1 (VDD), U22.1 (VDD); also elsewhere on the board
ADC2: IC4.8 (D); also elsewhere on the board
ADC3: IC3.8 (D); also elsewhere on the board
ADC4: IC2.8 (D); also elsewhere on the board
GND: C12.2, C13.2, C14.2, C15.2, C16.2, C17.2, IC2.3 (VSS), IC2.14 (GND), IC3.3 (VSS), IC3.14 (GND), IC4.3 (VSS), IC4.14 (GND), U3.3 (GND), U4.3 (GND), U5.3 (GND), U6.3 (GND), U7.3 (GND), U8.3 (GND), U9.3 (GND), U10.3 (GND), U11.3 (GND), U12.3 (GND), U13.3 (GND), U14.3 (GND), U15.3 (GND), U16.3 (GND), U17.3 (GND), U18.3 (GND), U19.3 (GND), U20.3 (GND), U21.3 (GND), U22.3 (GND); also elsewhere on the board
MUX1_A: IC4.1 (A0); also elsewhere on the board
MUX1_B: IC4.16 (A1); also elsewhere on the board
MUX1_C: IC4.15 (A2); also elsewhere on the board
MUX2_A: IC2.1 (A0), IC3.1 (A0); also elsewhere on the board
MUX2_B: IC2.16 (A1), IC3.16 (A1); also elsewhere on the board
MUX2_C: IC2.15 (A2), IC3.15 (A2); also elsewhere on the board
SENS_A_S1: IC2.7 (S4), U10.2 (OUT)
SENS_A_S2: IC2.9 (S8), U3.2 (OUT)
SENS_A_S3: IC2.10 (S7), U4.2 (OUT)
SENS_A_S4: IC2.11 (S6), U5.2 (OUT)
SENS_A_S5: IC3.5 (S2), U9.2 (OUT)
SENS_A_S6: IC3.6 (S3), U8.2 (OUT)
SENS_A_S7: IC3.7 (S4), U7.2 (OUT)
SENS_A_S8: IC2.12 (S5), U6.2 (OUT)
SENS_B_S1: IC4.12 (S5), U18.2 (OUT)
SENS_B_S2: IC3.4 (S1), U17.2 (OUT)
SENS_B_S3: IC2.6 (S3), U11.2 (OUT)
SENS_B_S4: IC2.5 (S2), U12.2 (OUT)
SENS_B_S5: IC4.9 (S8), U14.2 (OUT)
SENS_B_S6: IC4.10 (S7), U15.2 (OUT)
SENS_B_S7: IC4.11 (S6), U16.2 (OUT)
SENS_B_S8: IC2.4 (S1), U13.2 (OUT)
SENS_C_S4: IC4.7 (S4), U19.2 (OUT)
SENS_C_S5: IC4.5 (S2), U22.2 (OUT)
SENS_C_S6: IC3.9 (S8), U21.2 (OUT)
SENS_C_S8: IC4.6 (S3), U20.2 (OUT)

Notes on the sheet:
KeySwitches
HallSensors
Analog Multiplexers

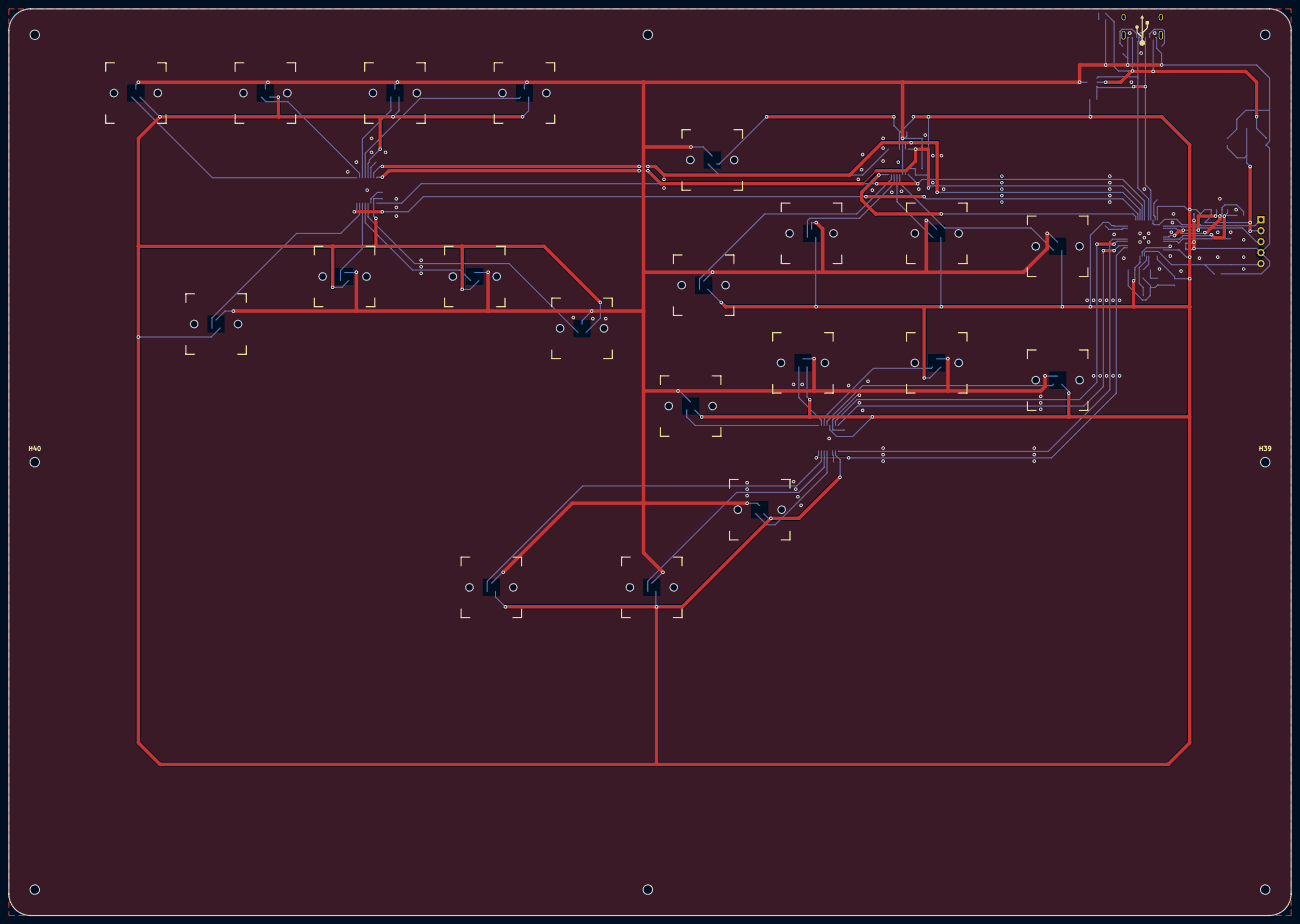
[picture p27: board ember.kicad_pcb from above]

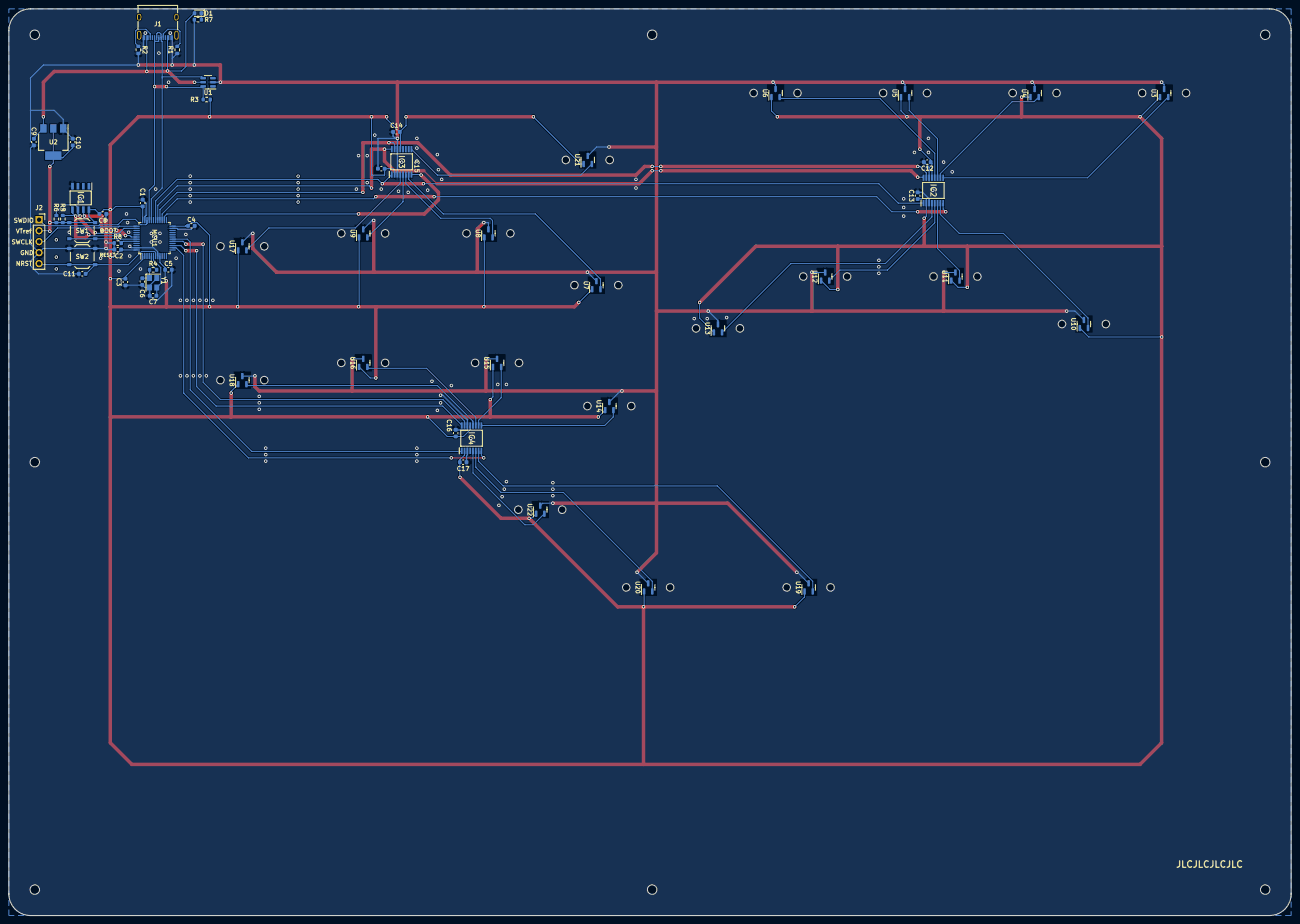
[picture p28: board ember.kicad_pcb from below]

Board: 2 copper layers, 297.0 x 210.0 mm, 86 parts (58 on the bottom side), 47 nets.

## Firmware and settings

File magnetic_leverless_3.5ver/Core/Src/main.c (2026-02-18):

/* main.c */
#include "main.h"
#include "adc.h"
#include "usb_device.h"
#include "gpio.h"
#include "usbd_hid.h"
#include <stdint.h>
#include <stdbool.h>
#include <string.h>
#include <stdlib.h>
#include <math.h>

// --- 定数定義 (Jade Pro用) ---
#define KEY_COUNT 20
#define TRAVEL_DISTANCE_MM 3.5f  // ★Jade Pro用に3.5mmへ変更
#define ADC_MAX 4095.0f
#define RAW_DEADZONE 60 

// WebHID Commands
#define CMD_GET_CONFIG    0x10 
#define CMD_GET_COMBOS    0x11
#define CMD_SET_CONFIG    0x20 
#define CMD_READ_SENSORS  0x30 
#define CMD_CALIBRATE     0x40 
#define CMD_SAVE_SETTINGS 0x50 
#define CMD_SET_SOCD      0x60 
#define CMD_SET_MAPPING   0x70 
#define CMD_STOP_INPUT    0x80 
#define CMD_SET_COMBO     0x81 

// Flash Memory
#define FLASH_STORAGE_ADDR 0x0801F800
#define FLASH_MAGIC_NUM    0xDEADBEE3 

// --- ボタンID定義 ---
#define BTN_NONE      0
#define BTN_UP        1
#define BTN_DOWN      2
#define BTN_LEFT      3
#define BTN_RIGHT     4
#define BTN_START     5
#define BTN_BACK      6
#define BTN_L3        7
#define BTN_R3        8
#define BTN_LB        9
#define BTN_RB        10
#define BTN_GUIDE     11
#define BTN_A         12
#define BTN_B         13
#define BTN_X         14
#define BTN_Y         15
#define BTN_LT        16 
#define BTN_RT        17 
// コンボボタンID
#define BTN_COMBO_1   100
#define BTN_COMBO_2   101
#define BTN_COMBO_3   102
#define BTN_COMBO_4   103

// XInput Bitmask
#define XINPUT_DPAD_UP    0x0001
#define XINPUT_DPAD_DOWN  0x0002
#define XINPUT_DPAD_LEFT  0x0004
#define XINPUT_DPAD_RIGHT 0x0008
#define XINPUT_START      0x0010
#define XINPUT_BACK       0x0020
#define XINPUT_LB         0x0100
#define XINPUT_RB         0x0200
#define XINPUT_BTN_A      0x1000
#define XINPUT_BTN_B      0x2000
#define XINPUT_BTN_X      0x4000
#define XINPUT_BTN_Y      0x8000
#define XINPUT_THUMB_L    0x0040
#define XINPUT_THUMB_R    0x0080
#define XINPUT_GUIDE      0x0400

#define COMBO_COUNT 4

// --- キーマップ (デフォルト) ---
uint8_t key_map[KEY_COUNT] = {
    BTN_RIGHT, BTN_DOWN, BTN_LEFT, BTN_R3, BTN_L3, BTN_GUIDE, BTN_BACK, BTN_START, 
    BTN_RB,    BTN_LB,   BTN_Y,    BTN_X,  BTN_R3, BTN_A,     BTN_B,    BTN_LT, 
    BTN_RT,    BTN_L3,   BTN_UP,   BTN_R3
};

// --- 構造体 ---
typedef struct {
    uint16_t resting_val;
    uint16_t max_diff;
    float current_mm;
    float anchor_mm;
    bool is_pressed;
    
    // 設定値
    float actuation_point;
    float rt_press;
    float rt_release;
    float top_deadzone;
    float bottom_deadzone;
} KeyState_t;

typedef struct {
    uint16_t mask; 
    uint8_t lt;    
    uint8_t rt;    
} ComboSetting_t;

// Flash保存用構造体
typedef struct {
    uint32_t magic;
    float ap[KEY_COUNT];
    float rt[KEY_COUNT];
    float top_dz[KEY_COUNT];
    float bottom_dz[KEY_COUNT];
    uint8_t socd_mode;
    uint8_t key_map[KEY_COUNT];
    ComboSetting_t combos[COMBO_COUNT];
    uint8_t reserved[3];
} FlashConfig_t;

typedef struct __attribute__((packed)) {
    uint8_t msg_type; uint8_t pkt_size; 
    uint16_t buttons; uint8_t lt; uint8_t rt;
    int16_t lx; int16_t ly; int16_t rx; int16_t ry; 
    uint8_t reserved[6]; 
} XInputReport_t;

// --- グローバル変数 ---
extern USBD_HandleTypeDef hUsbDeviceFS;
extern ADC_HandleTypeDef hadc2;
extern ADC_HandleTypeDef hadc3;
extern ADC_HandleTypeDef hadc4;

uint8_t g_boot_mode = 0; 
volatile bool g_req_calibrate = false;
volatile bool g_req_save = false;
volatile bool g_input_enabled = true; 

uint8_t g_socd_mode = 0; 
ComboSetting_t g_combos[COMBO_COUNT];

// Last Win用
bool last_left_state = false;
bool last_right_state = false;
bool last_up_state = false;
bool last_down_state = false;
int  last_lr_winner = 0; 
int  last_ud_winner = 0; 

uint16_t adc_raw_values[KEY_COUNT];
KeyState_t key_states[KEY_COUNT];
uint8_t webhid_tx_buf[64];

// --- プロトタイプ宣言 ---
void SystemClock_Config(void);
void Error_Handler(void);
void MUX1_Select(uint8_t ch);
void MUX2_Select(uint8_t ch);
void scan_all_keys_fast(uint16_t *buffer);
void Process_Rapid_Trigger(int key_idx, uint16_t raw_val);
void Send_Reports(void);
void Save_Config(void);
void Load_Config(void);
extern uint8_t USBD_WebHID_SendReport(USBD_HandleTypeDef *pdev, uint8_t *report, uint16_t len);
extern uint8_t USBD_HID_SendReport(USBD_HandleTypeDef *pdev, uint8_t *report, uint16_t len);

// --- 初期化 ---
void Setup_Keys(void) {
    HAL_Delay(100);
    scan_all_keys_fast(adc_raw_values);
    HAL_Delay(50);
    scan_all_keys_fast(adc_raw_values);

    for(int i=0; i<KEY_COUNT; i++) {
        key_states[i].resting_val = adc_raw_values[i];
        key_states[i].max_diff = 200; 
        
        // デフォルト値 (Jade Pro 3.5mm用)
        key_states[i].actuation_point = 1.2f;
        key_states[i].rt_press = 0.5f;
        key_states[i].rt_release = 0.5f;
        key_states[i].top_deadzone = 0.2f;
        key_states[i].bottom_deadzone = 0.1f;
        
        key_states[i].is_pressed = false;
        key_states[i].anchor_mm = 0.0f;
        key_states[i].current_mm = 0.0f;
    }
    g_socd_mode = 0; 
    for(int i=0; i<COMBO_COUNT; i++) {
        g_combos[i].mask = 0; g_combos[i].lt = 0; g_combos[i].rt = 0;
    }
}

// --- Flash 保存/読み込み ---
void Save_Config(void) {
    FlashConfig_t cfg;
    cfg.magic = FLASH_MAGIC_NUM;
    cfg.socd_mode = g_socd_mode;
    for(int i=0; i<KEY_COUNT; i++) {
        cfg.ap[i] = key_states[i].actuation_point;
        cfg.rt[i] = key_states[i].rt_press;
        cfg.top_dz[i] = key_states[i].top_deadzone;
        cfg.bottom_dz[i] = key_states[i].bottom_deadzone;
        cfg.key_map[i] = key_map[i];
    }
    for(int i=0; i<COMBO_COUNT; i++) cfg.combos[i] = g_combos[i];

    HAL_FLASH_Unlock();
    FLASH_EraseInitTypeDef EraseInitStruct;
    uint32_t PageError;
    EraseInitStruct.TypeErase = FLASH_TYPEERASE_PAGES;
    EraseInitStruct.PageAddress = FLASH_STORAGE_ADDR;
    EraseInitStruct.NbPages = 1;

    if (HAL_FLASHEx_Erase(&EraseInitStruct, &PageError) == HAL_OK) {
        uint32_t *pData = (uint32_t*)&cfg;
        for (int i = 0; i < sizeof(FlashConfig_t) / 4; i++) {
            HAL_FLASH_Program(FLASH_TYPEPROGRAM_WORD, FLASH_STORAGE_ADDR + (i * 4), pData[i]);
        }
    }
    HAL_FLASH_Lock();
}

void Load_Config(void) {
    FlashConfig_t *pCfg = (FlashConfig_t*)FLASH_STORAGE_ADDR;
    if (pCfg->magic == FLASH_MAGIC_NUM) {
        g_socd_mode = pCfg->socd_mode;
        for(int i=0; i<KEY_COUNT; i++) {
            key_states[i].actuation_point = pCfg->ap[i];
            key_states[i].rt_press = pCfg->rt[i];
            key_states[i].rt_release = pCfg->rt[i];
            key_states[i].top_deadzone = pCfg->top_dz[i];
            key_states[i].bottom_deadzone = pCfg->bottom_dz[i];
            key_map[i] = pCfg->key_map[i];
        }
        for(int i=0; i<COMBO_COUNT; i++) g_combos[i] = pCfg->combos[i];
    }
}

// --- MUX制御 ---
void short_delay(void) { for(volatile int i = 0; i < 30; i++) { __NOP(); } }
void MUX1_Select(uint8_t ch) {
    HAL_GPIO_WritePin(MUX1_A_GPIO_Port, MUX1_A_Pin, (ch & 0x01) ? GPIO_PIN_SET : GPIO_PIN_RESET);
    HAL_GPIO_WritePin(MUX1_B_GPIO_Port, MUX1_B_Pin, (ch & 0x02) ? GPIO_PIN_SET : GPIO_PIN_RESET);
    HAL_GPIO_WritePin(MUX1_C_GPIO_Port, MUX1_C_Pin, (ch & 0x04) ? GPIO_PIN_SET : GPIO_PIN_RESET);
}
void MUX2_Select(uint8_t ch) {
    HAL_GPIO_WritePin(MUX2_A_GPIO_Port, MUX2_A_Pin, (ch & 0x01) ? GPIO_PIN_SET : GPIO_PIN_RESET);
    HAL_GPIO_WritePin(MUX2_B_GPIO_Port, MUX2_B_Pin, (ch & 0x02) ? GPIO_PIN_SET : GPIO_PIN_RESET);
    HAL_GPIO_WritePin(MUX2_C_GPIO_Port, MUX2_C_Pin, (ch & 0x04) ? GPIO_PIN_SET : GPIO_PIN_RESET);
}

// --- ADCスキャン ---
void scan_all_keys_fast(uint16_t *buffer) {
    for (int ch = 0; ch < 8; ch++) {
        MUX2_Select(ch); MUX1_Select(ch); short_delay(); 
        HAL_ADC_Start(&hadc4); HAL_ADC_Start(&hadc3); HAL_ADC_Start(&hadc2);
        if (HAL_ADC_PollForConversion(&hadc4, 1) == HAL_OK) buffer[ch] = HAL_ADC_GetValue(&hadc4);
        if (HAL_ADC_PollForConversion(&hadc3, 1) == HAL_OK) {
            uint16_t val = HAL_ADC_GetValue(&hadc3);
            if (ch < 4) buffer[ch + 8] = val; else if (ch == 7) buffer[12] = val; 
        }
        if (HAL_ADC_PollForConversion(&hadc2, 1) == HAL_OK) {
            uint16_t val = HAL_ADC_GetValue(&hadc2);
            switch(ch) { 
                case 7: buffer[13]=val; break; case 6: buffer[14]=val; break; 
                case 5: buffer[15]=val; break; case 4: buffer[16]=val; break; 
                case 3: buffer[17]=val; break; case 2: buffer[18]=val; break; 
                case 1: buffer[19]=val; break; 
            }
        }
    }
}

// --- ラピッドトリガー (AP優先・Jade Pro 3.5mm対応) ---
void Process_Rapid_Trigger(int key_idx, uint16_t raw) {
    KeyState_t *k = &key_states[key_idx];
    int diff = (int)raw - (int)k->resting_val;
    uint16_t abs_diff = abs(diff);

    if (abs_diff < RAW_DEADZONE) abs_diff = 0;
    if (abs_diff > k->max_diff) k->max_diff = abs_diff;

    float norm = (float)abs_diff / (float)k->max_diff;
    if (norm > 1.0f) norm = 1.0f;
    
    // Jade Pro 3.5mm
    float pos = norm * TRAVEL_DISTANCE_MM;

    if (pos < k->top_deadzone) pos = 0.0f;
    k->current_mm = pos;

    bool in_bottom_zone = (pos > (TRAVEL_DISTANCE_MM - k->bottom_deadzone));

    // 1. AP以下の処理 (絶対優先: OFF)
    if (pos < k->actuation_point) {
        k->is_pressed = false;
        k->anchor_mm = pos; // 常に最下点を追従
        return;
    }

    // 2. AP以上の処理
    if (k->is_pressed) {
        // 現在ONの場合: リリース判定
        
        // より深く押し込んだ場合、アンカー(最深点)を更新
        if (pos > k->anchor_mm) {
            k->anchor_mm = pos;
        }
        // RTリリース判定
        else if (pos < (k->anchor_mm - k->rt_release)) {
            if (!in_bottom_zone) {
                k->is_pressed = false;
                k->anchor_mm = pos;
            } else {
                k->anchor_mm = pos;
            }
        }
    } 
    else {
        // 現在OFFの場合: プレス判定
        
        // ケースA: APより下から突き上げてきた場合 (即座にON)
        if (k->anchor_mm < k->actuation_point) {
            k->is_pressed = true;
            k->anchor_mm = pos;
        }
        // ケースB: ラピッドトリガー再点火 (APより上で浮かせた状態からの再入力)
        else if (pos > (k->anchor_mm + k->rt_press)) {
            k->is_pressed = true;
            k->anchor_mm = pos;
        }
        // まだONにならない場合、アンカー(最浅点)を更新して追従
        else if (pos < k->anchor_mm) {
            k->anchor_mm = pos;
        }
    }
}

// --- レポート送信 ---
void Send_Reports(void) {
    static XInputReport_t prev_report = {0};
    XInputReport_t report = {0};
    report.msg_type = 0x00;
    report.pkt_size = 0x14;

    if (!g_input_enabled) {
        if (memcmp(&report, &prev_report, sizeof(XInputReport_t)) != 0) {
            if (USBD_HID_SendReport(&hUsbDeviceFS, (uint8_t*)&report, sizeof(report)) == USBD_OK) {
                prev_report = report;
            }
        }
        return;
    }

    uint16_t btns_mask = 0;
    uint8_t trigger_l = 0;
    uint8_t trigger_r = 0;
    bool up=false, down=false, left=false, right=false;

    for(int i = 0; i < KEY_COUNT; i++) {
        if (key_states[i].is_pressed) {
            uint8_t id = key_map[i];
            
            if (id >= BTN_COMBO_1 && id <= BTN_COMBO_4) {
                int combo_idx = id - BTN_COMBO_1;
                if (combo_idx < COMBO_COUNT) {
                    btns_mask |= g_combos[combo_idx].mask;
                    if (g_combos[combo_idx].lt) trigger_l = 255;
                    if (g_combos[combo_idx].rt) trigger_r = 255;
                    if (g_combos[combo_idx].mask & XINPUT_DPAD_UP) up = true;
                    if (g_combos[combo_idx].mask & XINPUT_DPAD_DOWN) down = true;
                    if (g_combos[combo_idx].mask & XINPUT_DPAD_LEFT) left = true;
                    if (g_combos[combo_idx].mask & XINPUT_DPAD_RIGHT) right = true;
                }
                continue;
            }

            switch(id) {
                case BTN_UP:    up=true; break;
                case BTN_DOWN:  down=true; break;
                case BTN_LEFT:  left=true; break;
                case BTN_RIGHT: right=true; break;
                case BTN_START: btns_mask |= XINPUT_START; break;
                case BTN_BACK:  btns_mask |= XINPUT_BACK; break;
                case BTN_L3:    btns_mask |= XINPUT_THUMB_L; break;
                case BTN_R3:    btns_mask |= XINPUT_THUMB_R; break;
                case BTN_LB:    btns_mask |= XINPUT_LB; break;
                case BTN_RB:    btns_mask |= XINPUT_RB; break;
                case BTN_GUIDE: btns_mask |= XINPUT_GUIDE; break;
                case BTN_A:     btns_mask |= XINPUT_BTN_A; break;
                case BTN_B:     btns_mask |= XINPUT_BTN_B; break;
                case BTN_X:     btns_mask |= XINPUT_BTN_X; break;
                case BTN_Y:     btns_mask |= XINPUT_BTN_Y; break;
                case BTN_LT:    trigger_l = 255; break;
                case BTN_RT:    trigger_r = 255; break;
                default: break;
            }
        }
    }

    if (g_socd_mode == 2) {
        if (left && !last_left_state) last_lr_winner = -1;
        if (right && !last_right_state) last_lr_winner = 1;
        if (up && !last_up_state) last_ud_winner = 1;
        if (down && !last_down_state) last_ud_winner = -1;
        last_left_state = left; last_right_state = right;
        last_up_state = up; last_down_state = down;
    }

    if (left && right) {
        if (g_socd_mode == 0) { }
        else if (g_socd_mode == 1) { }
        else if (g_socd_mode == 2) { 
            if (last_lr_winner == -1) btns_mask |= XINPUT_DPAD_LEFT;
            else btns_mask |= XINPUT_DPAD_RIGHT;
        }
    } else {
        if (left) btns_mask |= XINPUT_DPAD_LEFT;
        if (right) btns_mask |= XINPUT_DPAD_RIGHT;
    }
    
    if (up && down) { 
        if (g_socd_mode == 0) { }
        else if (g_socd_mode == 1) { btns_mask |= XINPUT_DPAD_UP; } 
        else if (g_socd_mode == 2) { 
            if (last_ud_winner == 1) btns_mask |= XINPUT_DPAD_UP;
            else btns_mask |= XINPUT_DPAD_DOWN;
        }
    } else {
        if (up) btns_mask |= XINPUT_DPAD_UP;
        if (down) btns_mask |= XINPUT_DPAD_DOWN;
    }

    report.buttons = btns_mask;
    report.lt = trigger_l;
    report.rt = trigger_r;

    if (memcmp(&report, &prev_report, sizeof(XInputReport_t)) != 0) {
        if (USBD_HID_SendReport(&hUsbDeviceFS, (uint8_t*)&report, sizeof(report)) == USBD_OK) {
            prev_report = report;
        }
    }
}

// --- WebHID コールバック ---
void WebHID_DataReceived_Callback(uint8_t* data, uint32_t len) {
    uint8_t cmd = data[0]; 
    
    if (cmd == CMD_READ_SENSORS) {
        static uint8_t tx[64];
        memset(tx, 0, 64);
        tx[0] = CMD_READ_SENSORS;
        for(int i=0; i<KEY_COUNT; i++) {
            float val = key_states[i].current_mm / TRAVEL_DISTANCE_MM;
            if (val > 1.0f) val = 1.0f; else if (val < 0.0f) val = 0.0f;
            tx[i+1] = (uint8_t)(val * 255.0f);
        }
        for(int i=0; i<KEY_COUNT; i++) tx[i+21] = key_states[i].is_pressed ? 1 : 0;
        for(int i=0; i<KEY_COUNT; i++) {
            float val = key_states[i].anchor_mm / TRAVEL_DISTANCE_MM;
            if (val > 1.0f) val = 1.0f; else if (val < 0.0f) val = 0.0f;
            tx[i+41] = (uint8_t)(val * 255.0f);
        }
        USBD_WebHID_SendReport(&hUsbDeviceFS, tx, 64);
    }
    else if (cmd == CMD_GET_CONFIG) { 
        static uint8_t tx[64];
        memset(tx, 0, 64);
        tx[0] = CMD_GET_CONFIG;
        tx[1] = g_socd_mode;
        for(int i=0; i<KEY_COUNT; i++) tx[i+2] = (uint8_t)(key_states[i].actuation_point * 10.0f);
        for(int i=0; i<KEY_COUNT; i++) tx[i+22] = (uint8_t)(key_states[i].rt_press * 10.0f);
        for(int i=0; i<KEY_COUNT; i++) tx[i+42] = key_map[i];
        USBD_WebHID_SendReport(&hUsbDeviceFS, tx, 64);
    }
    else if (cmd == CMD_GET_COMBOS) {
        static uint8_t tx[64];
        memset(tx, 0, 64);
        tx[0] = CMD_GET_COMBOS;
        for(int i=0; i<COMBO_COUNT; i++) {
            int offset = 1 + (i * 4);
            tx[offset] = g_combos[i].mask & 0xFF;
            tx[offset+1] = (g_combos[i].mask >> 8) & 0xFF;
            tx[offset+2] = g_combos[i].lt;
            tx[offset+3] = g_combos[i].rt;
        }
        USBD_WebHID_SendReport(&hUsbDeviceFS, tx, 64);
    }
    else if (cmd == CMD_SET_CONFIG) {
        uint8_t id = data[1];
        if (id < KEY_COUNT) {
            float ap = (float)data[2] / 10.0f;
            if (ap < 0.1f) ap = 0.1f; 
            if (ap > 3.0f) ap = 3.0f;
            key_states[id].actuation_point = ap;

            float rt = (float)data[3] / 10.0f;
            if (rt < 0.1f) rt = 0.1f; 
            if (rt > 3.0f) rt = 3.0f;
            key_states[id].rt_press = rt; key_states[id].rt_release = rt;
            
            float top = (float)data[4] / 100.0f;
            float btm = (float)data[5] / 100.0f;
            key_states[id].top_deadzone = top;
            key_states[id].bottom_deadzone = btm;
        }
    }
    else if (cmd == CMD_SET_SOCD) { g_socd_mode = data[1]; }
    else if (cmd == CMD_SET_MAPPING) { 
        uint8_t id = data[1];
        uint8_t btn = data[2];
        if (id < KEY_COUNT) key_map[id] = btn;
    }
    else if (cmd == CMD_CALIBRATE) { g_req_calibrate = true; }
    else if (cmd == CMD_SAVE_SETTINGS) { g_req_save = true; }
    else if (cmd == CMD_STOP_INPUT) { g_input_enabled = (data[1] == 1); }
    else if (cmd == CMD_SET_COMBO) {
        uint8_t idx = data[1];
        if (idx < COMBO_COUNT) {
            g_combos[idx].mask = (data[3] << 8) | data[2];
            g_combos[idx].lt = data[4];
            g_combos[idx].rt = data[5];
        }
    }
}

// --- Main ---
int main(void) {
    HAL_Init();
    SystemClock_Config();
    MX_GPIO_Init();
    MX_ADC2_Init();
    MX_ADC3_Init();
    MX_ADC4_Init();
    
    HAL_Delay(100);
    scan_all_keys_fast(adc_raw_values);
    
    int diff_up_down = abs((int)adc_raw_values[18] - (int)adc_raw_values[1]);
    
    if (diff_up_down > 500) { 
        g_boot_mode = 1; 
        
        uint32_t start_tick = HAL_GetTick();
        while ((HAL_GetTick() - start_tick) < 5000) { 
            scan_all_keys_fast(adc_raw_values);
            int current_diff = abs((int)adc_raw_values[18] - (int)adc_raw_values[1]);
            if (current_diff < 300) { 
                break;
            }
            HAL_Delay(10);
        }
        HAL_Delay(500);
        
    } else { 
        g_boot_mode = 0; 
    }

    Setup_Keys(); 
    Load_Config();

    MX_USB_DEVICE_Init();
    
    while (1) {
        if (g_req_calibrate) { HAL_Delay(100); Setup_Keys(); g_req_calibrate = false; }
        if (g_req_save) { Save_Config(); g_req_save = false; }

        scan_all_keys_fast(adc_raw_values);
        for(int i=0; i<KEY_COUNT; i++) Process_Rapid_Trigger(i, adc_raw_values[i]);

        if (g_boot_mode == 0) Send_Reports();
    }
}

void SystemClock_Config(void) {
  RCC_OscInitTypeDef RCC_OscInitStruct = {0};
  RCC_ClkInitTypeDef RCC_ClkInitStruct = {0};
  RCC_PeriphCLKInitTypeDef PeriphClkInit = {0};
  RCC_OscInitStruct.OscillatorType = RCC_OSCILLATORTYPE_HSE;
  RCC_OscInitStruct.HSEState = RCC_HSE_ON;
  RCC_OscInitStruct.HSEPredivValue = RCC_HSE_PREDIV_DIV2; 
  RCC_OscInitStruct.HSIState = RCC_HSI_ON;
  RCC_OscInitStruct.PLL.PLLState = RCC_PLL_ON;
  RCC_OscInitStruct.PLL.PLLSource = RCC_PLLSOURCE_HSE;
  RCC_OscInitStruct.PLL.PLLMUL = RCC_PLL_MUL9; 
  if (HAL_RCC_OscConfig(&RCC_OscInitStruct) != HAL_OK) Error_Handler();
  RCC_ClkInitStruct.ClockType = RCC_CLOCKTYPE_HCLK|RCC_CLOCKTYPE_SYSCLK|RCC_CLOCKTYPE_PCLK1|RCC_CLOCKTYPE_PCLK2;
  RCC_ClkInitStruct.SYSCLKSource = RCC_SYSCLKSOURCE_PLLCLK;
  RCC_ClkInitStruct.AHBCLKDivider = RCC_SYSCLK_DIV1;
  RCC_ClkInitStruct.APB1CLKDivider = RCC_HCLK_DIV2;
  RCC_ClkInitStruct.APB2CLKDivider = RCC_HCLK_DIV1;
  if (HAL_RCC_ClockConfig(&RCC_ClkInitStruct, FLASH_LATENCY_2) != HAL_OK) Error_Handler();
  PeriphClkInit.PeriphClockSelection = RCC_PERIPHCLK_USB|RCC_PERIPHCLK_ADC12|RCC_PERIPHCLK_ADC34;
  PeriphClkInit.Adc12ClockSelection = RCC_ADC12PLLCLK_DIV1;
  PeriphClkInit.Adc34ClockSelection = RCC_ADC34PLLCLK_DIV1;
  PeriphClkInit.USBClockSelection = RCC_USBCLKSOURCE_PLL_DIV1_5; 
  if (HAL_RCCEx_PeriphCLKConfig(&PeriphClkInit) != HAL_OK) Error_Handler();
}
void Error_Handler(void) { __disable_irq(); while (1) { } }

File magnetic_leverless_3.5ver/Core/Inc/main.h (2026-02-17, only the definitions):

#define MUX1_B_Pin GPIO_PIN_5
#define MUX1_B_GPIO_Port GPIOA
#define MUX1_C_Pin GPIO_PIN_7
#define MUX1_C_GPIO_Port GPIOA
#define MUX1_A_Pin GPIO_PIN_0
#define MUX1_A_GPIO_Port GPIOB
#define MUX2_C_Pin GPIO_PIN_15
#define MUX2_C_GPIO_Port GPIOB
#define MUX2_B_Pin GPIO_PIN_8
#define MUX2_B_GPIO_Port GPIOA
#define MUX2_A_Pin GPIO_PIN_9
#define MUX2_A_GPIO_Port GPIOA
#define USB_D__Pin GPIO_PIN_11
#define USB_D__GPIO_Port GPIOA
#define USB_D_A12_Pin GPIO_PIN_12
#define USB_D_A12_GPIO_Port GPIOA
#define SWDIO_Pin GPIO_PIN_13
#define SWDIO_GPIO_Port GPIOA
#define SWCLK_Pin GPIO_PIN_14
#define SWCLK_GPIO_Port GPIOA
#define SCL_Pin GPIO_PIN_15
#define SCL_GPIO_Port GPIOA
#define WC_Pin GPIO_PIN_6
#define WC_GPIO_Port GPIOB
#define SDA_Pin GPIO_PIN_7
#define SDA_GPIO_Port GPIOB

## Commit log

2026-02-17 完成版Ver1.0
2026-02-18 完全版Ver1.1
2026-02-18 Ver1.2訂正版
2026-02-18 readme編集
2026-02-18 特別仕様
2026-02-19 名称変更
2026-02-26 最終調整
2026-02-26 SN調整
2026-02-26 天板用画像追加

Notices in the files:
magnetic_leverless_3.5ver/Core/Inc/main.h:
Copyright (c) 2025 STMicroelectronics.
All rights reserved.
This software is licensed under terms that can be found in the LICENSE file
